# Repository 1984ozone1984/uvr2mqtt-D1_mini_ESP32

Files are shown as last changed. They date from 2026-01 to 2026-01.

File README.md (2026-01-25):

# UVR2MQTT - UVR1611 DL-Bus to MQTT Gateway

ESP32-based gateway that reads data from a Technische Alternative UVR1611 solar heating controller via DL-Bus and publishes to MQTT with Home Assistant auto-discovery.

## Hardware

- **Board**: Azdelivery D1 Mini ESP32 (ESP32-WROOM-32)
- **Connection**: DL-Bus via optocoupler to GPIO26
- **PCB Files**: KiCad schematic and PCB design files available in the `PCB/` folder, including Gerber files for manufacturing

## Features

### DL-Bus Protocol
- GPIO interrupt-based edge capture (bypasses RMT 512-symbol limitation)
- Dedicated high-priority interrupt on Core 1 (away from WiFi on Core 0)
- Manchester-like decoding with automatic polarity detection
- SYNC detection, checksum validation
- Full 64-byte frame parsing

### Sensor Data
- 16 temperature/flow/radiation sensors with configurable names
- 13 digital outputs (pumps, valves, mixers)
- 4 speed levels for variable-speed pumps
- 2 heat meters with power (kW) and energy (kWh)

### MQTT & Home Assistant
- WiFi connection with automatic reconnection
- MQTT client with Last Will and Testament (online/offline status)
- Home Assistant auto-discovery for all entities
- Configurable publish intervals
- Median filtering for sensor values
- Immediate publish on output state changes

### Web Configuration
- Built-in web UI for configuration (no rebuild required)
- WiFi STA/AP mode with automatic fallback
- Configure WiFi and MQTT settings via browser
- Edit all I/O names:
  - Sensor names (S1-S16)
  - Output names (A1-A13)
  - Speed level names (Drehzahlstufen A1, A2, A6, A7)
  - Heat meter names (WMZ1/WMZ2 power and energy)
- Disable entities by setting name to `---` or empty
- Live sensor and output status display
- Settings stored in NVS (persist across reboots)
- OTA firmware update via web browser

## Screenshots

### Web Interface - Status Page
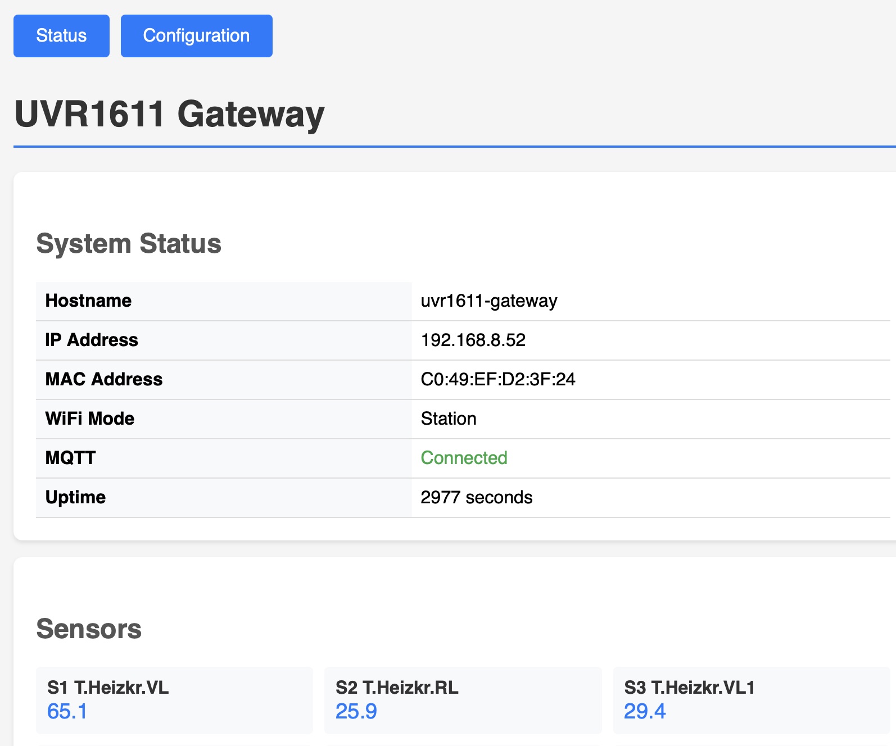
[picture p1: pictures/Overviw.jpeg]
Status Overview


### Live Sensor Data
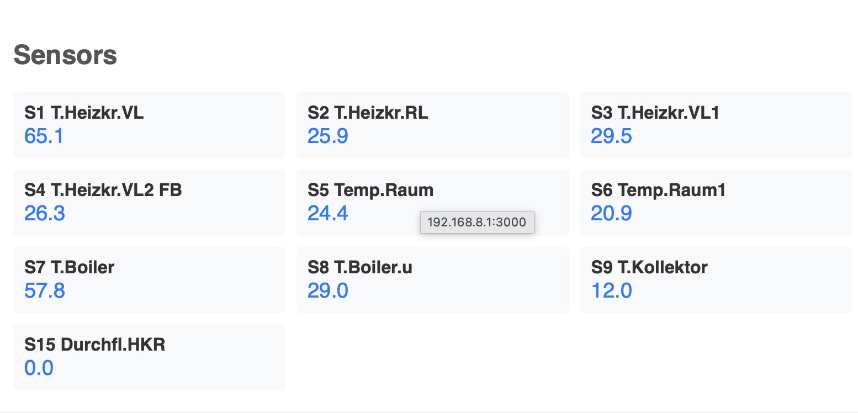
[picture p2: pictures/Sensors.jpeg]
Sensors


### Output States
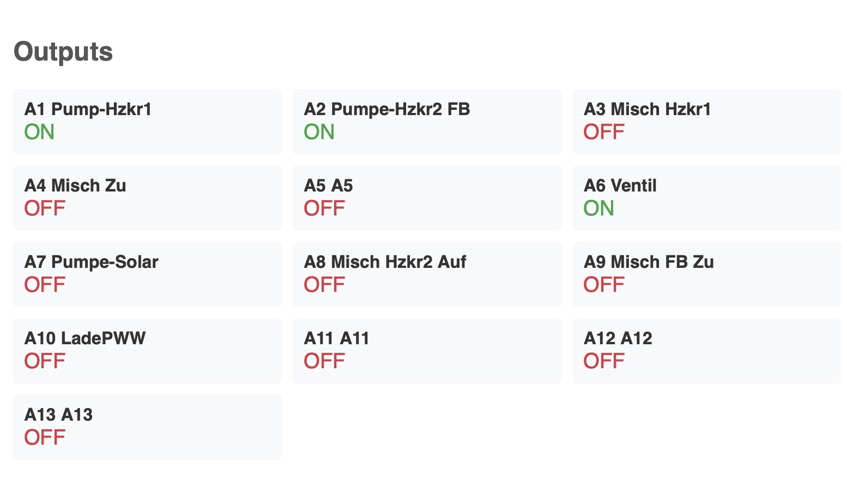
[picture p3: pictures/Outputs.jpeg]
Outputs


### WiFi Configuration
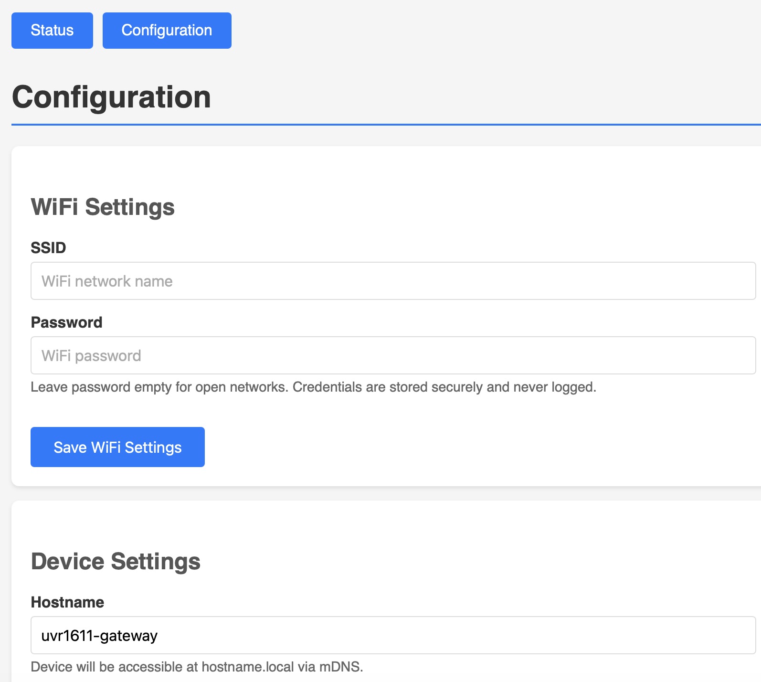
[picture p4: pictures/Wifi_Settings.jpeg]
WiFi Settings


### MQTT Configuration
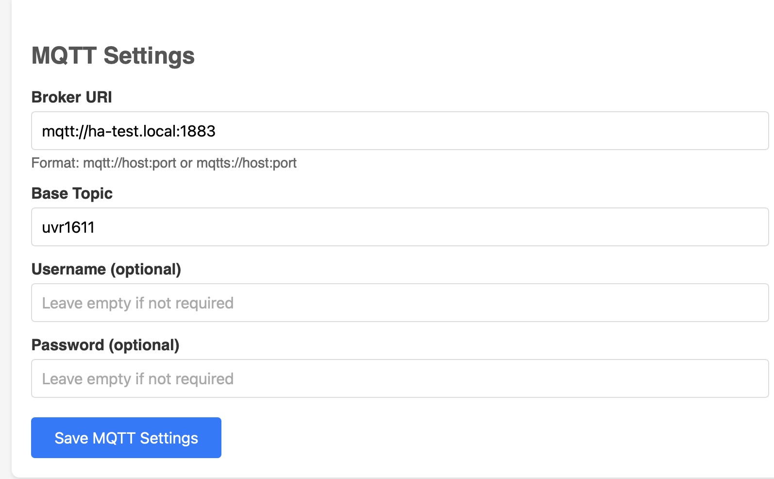
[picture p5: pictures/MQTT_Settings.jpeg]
MQTT Settings


### Home Assistant Integration
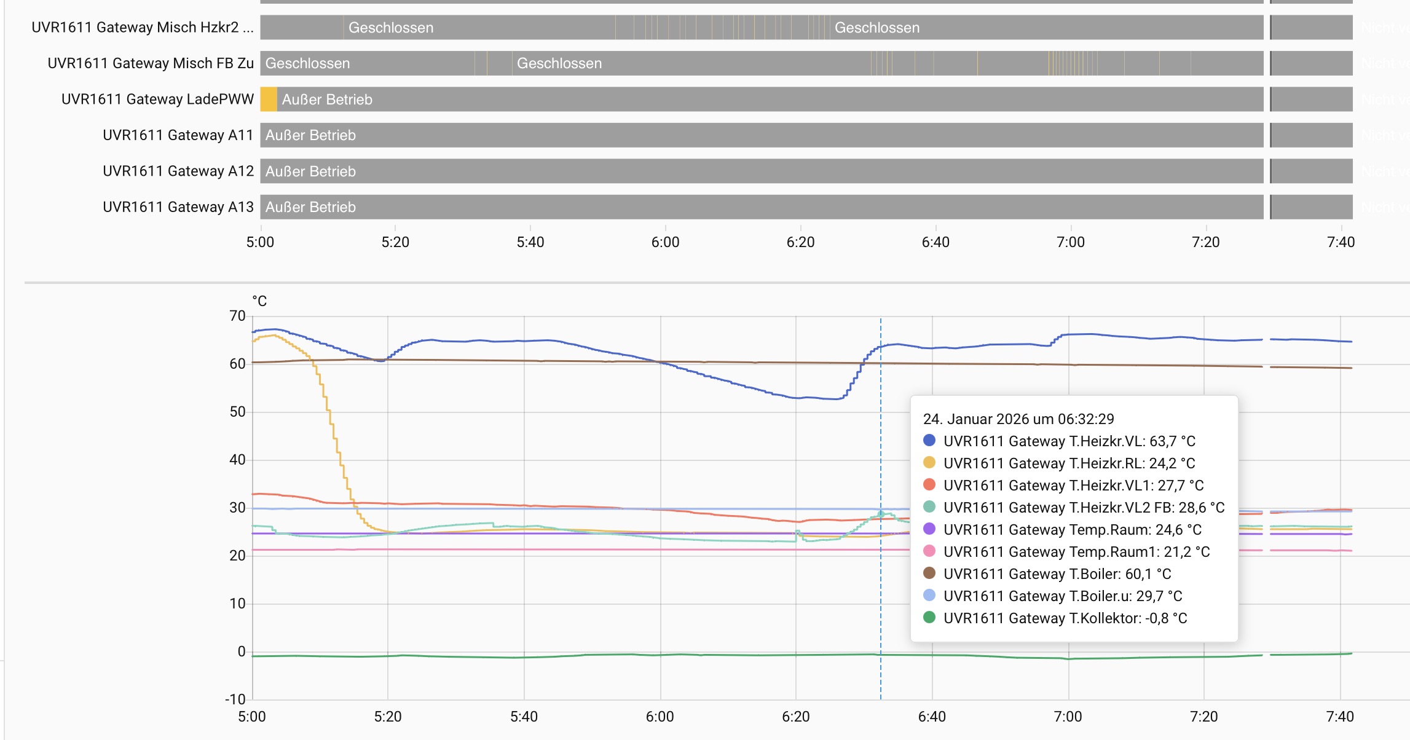
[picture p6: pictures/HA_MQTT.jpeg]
Home Assistant


## Configuration

### First Boot Setup (Web UI)

1. Flash the firmware to your ESP32
2. Device starts in AP mode (no credentials yet)
3. Connect to WiFi network **"UVR1611-XXXXXX"** (XXXXXX = last 6 chars of MAC address)
4. Open http://192.168.4.1 in your browser
5. Configure WiFi credentials and MQTT settings
6. Device saves settings and reboots
7. Device connects to your WiFi network
8. Access web UI via **http://uvr1611-gateway.local** or the device IP

### WiFi Modes

**STA Mode (Normal Operation)**:
- Connects to your configured WiFi network
- MQTT publishing active
- Web UI accessible at hostname.local

**AP Mode (Configuration/Fallback)**:
- Activates when no credentials or connection fails
- SSID: "UVR1611-XXXXXX"
- IP: 192.168.4.1
- Configure via web browser
- DL-Bus reading continues locally

### Configuring Sensors, Outputs, Speed Levels & Heat Meters

All I/O names are configurable via the web UI. **Only entities with configured names are published to MQTT and Home Assistant.** Use `---` or leave empty to disable an entity.

**Via Web UI (recommended):**
1. Go to the `/config` page
2. Scroll down to the I/O configuration section
3. Edit names for:
   - **Sensors S1-S16**: Temperature, flow, radiation sensors
   - **Outputs A1-A13**: Pumps, valves, mixers
   - **Speed Levels (Drehzahlstufen)**: Variable speed for A1, A2, A6, A7
   - **Heat Meters (Wärmemengenzähler)**: WMZ1/WMZ2 power (kW) and energy (kWh)
4. Click "Save I/O Names"
5. Changes take effect immediately for web display
6. **Reboot** to update MQTT topics and Home Assistant discovery

**Name Filtering:**
- Names must contain at least one letter or number to be published
- Names with only `-` characters (like `---`) are disabled
- Empty names are disabled
- Disabled entities do not appear in Home Assistant

**Example Configuration:**
| Entity | Name | Result |
|---|---|---|
| S1 | `T.Heizkr.VL` | ✅ Published |
| S10 | `---` | ❌ Disabled |
| S11 | ` ` (empty) | ❌ Disabled |
| WMZ1 Leistung | `Solar Leistung` | ✅ Published |
| WMZ2 Energie | `---` | ❌ Disabled |

**Via menuconfig (compile-time defaults):**
```bash
pio run -t menuconfig
```
Navigate to: "UVR1611 Configuration" → "Sensor Names", "Output Names", "Speed Level Names", or "Heat Meter Names"

### OTA Firmware Update

After initial USB flash, firmware can be updated via web browser:
1. Go to the `/config` page
2. Find "Firmware Update" section
3. Select new `.bin` firmware file
4. Click "Upload & Update Firmware"
5. Device reboots automatically with new firmware

## Building

Requires PlatformIO with ESP-IDF framework.

```bash
# Build
pio run

# Upload
pio run -t upload

# Monitor serial output
pio device monitor

# Configure sensor names
pio run -t menuconfig
```

## MQTT Topics

```
uvr1611/status                          # "online" / "offline" (LWT)
uvr1611/sensor/{sensor_name}/state      # Sensor value (median)
uvr1611/switch/{output_name}/state      # "ON" / "OFF"
uvr1611/sensor/{speed_name}/state       # Speed level (% or "inactive")
uvr1611/sensor/{hm_power_name}/state    # Heat meter power in kW
uvr1611/sensor/{hm_energy_name}/state   # Heat meter energy in kWh
uvr1611/system/mac                      # MAC address
uvr1611/system/ip                       # IP address
uvr1611/system/uptime                   # Uptime in seconds
```

Topic names are derived from configured names (lowercase, spaces/dots replaced with underscores).
Only entities with configured names (containing letters/numbers) are published.

## Home Assistant

Entities with configured names are automatically discovered via MQTT discovery. They appear under a single device with your configured hostname:
- Temperature sensors with proper device class
- Binary sensors for outputs (pumps, valves)
- Numeric sensors for speed levels (Drehzahlstufen)
- Power and energy sensors for heat meters (Wärmemengenzähler)
- System uptime sensor
- Diagnostic entities (IP address, MAC address, connectivity status)

**Note:** Only entities with names containing letters or numbers are registered. Use `---` to hide unused sensors/outputs from Home Assistant.

Change the device name by editing the hostname in the web UI and rebooting.

## Protocol Details

### DL-Bus Timing
- Display clock: 488 Hz
- Bit duration: 2.048 ms (2048 us)
- Half-bit duration: 1.024 ms (1024 us)

### Frame Structure
- SYNC: 16 high bits
- Data: 64 bytes (start bit + 8 data bits + stop bit per byte)
- Checksum: Sum of bytes 0-62 mod 256

### Sensor Types
| Type | Description | Encoding |
|---|---|---|
| 0x00 | Unused | - |
| 0x10 | Digital | Bit 7 of high byte |
| 0x20 | Temperature | 12-bit signed, /10 for °C |
| 0x30 | Flow rate | 12-bit × 4 l/h |
| 0x60 | Radiation | 12-bit W/m² |
| 0x70 | Room sensor | 9-bit signed, /10 for °C |

## Architecture

```
GPIO26 (Core 1) ─► Edge Buffer ─► Bit Extractor ─► Manchester Decoder ─► Frame Queue
                                    (Core 1)          (Core 1)              │
                                                                            ▼
WiFi/MQTT (Core 0) ◄────────────────────────────────────────────── Main Loop
```

- DL-Bus capture runs entirely on Core 1 to avoid WiFi interference
- WiFi power save disabled for consistent interrupt timing
- Dedicated GPIO interrupt (not shared ISR service) for lower latency

## Status

**All Phases Complete**:
- DL-Bus decoding: 0.2% error rate
- All sensor types parsed correctly
- MQTT publishing working
- Home Assistant auto-discovery working
- Web-based configuration UI working
- WiFi STA/AP mode with auto-fallback working
- Sensor/output name editing via web UI
- OTA firmware update via web browser

## License

MIT

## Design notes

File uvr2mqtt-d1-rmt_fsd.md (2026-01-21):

# Functional Specification Document: UVR1611 DL-Bus Reader (Simple Version)

## Project Goal
ESP32 reads UVR1611 DL-Bus data and outputs parsed values to Serial Monitor for testing and debugging.

## Hardware

### ESP32 Board
- **Azdelivery D1 Mini ESP32**
- SoC ESP32-WROOM-32
- CPU Xtensa® single-dual-core 32-bit LX6
- Chipset ESP32-D0WDQ6
- Clock frequency range 80MHz / 240MHz
- RAM 512kB
- External flash memory 4MB
- I/O pins 34
- ADC channels 18
- ADC Resolution 12-bit
- DAC channels 2
- DAC Resolution 8-bit
- Communication interfaces SPI, I2C, I2S, CAN, UART
- Max. current drawn per GPIO pin 40mA
- Wi-Fi protocols 802.11 b/g/n (802.11n up to 150 Mbps)
- Wi-Fi frequency 2.4 GHz - 2.5 GHz
- Bluetooth V4.2 - BLE and Classic Bluetooth
- Wireless antena PCB
- USB to serial chip CP2104
- Dimensions 39x28x6mm (1.5x1.1x0.2in)
- Documentation: `docs/D1 Mini ESP32_EN.pdf`

### Pin Configuration
- **DL-Bus RX Pin:** GPIO26
- **GND:** GND pin
- **Power:** 5V via USB-C or 3.3V from pin

### UVR1611 Connection
```
UVR1611 DL-Bus → Optocoupler Output → Azdelivery D1 Mini ESP32 GPIO26
                 Optocoupler GND    → Azdelivery D1 Mini ESP32 GND
```

## UVR1611 Protocol Specification

### Reference Documents
- **Protocol Specification**: `docs/Datenleitung.PDF`
- Complete DL-Bus interface documentation

### Protocol Basics
- **Display clock:** 488 Hz
- **Encoding Type:** Manchester
- **Polarity/Convention:** rising edge = 1 high
- **Sync:** 16 high bits Byte 0
- **Bit duration:** 2.048 ms
- **Frame duration:** ~1.35 seconds
- **Frame size:** 65 bytes total
- **Device ID:** 0x80 (UVR1611)
- **Device ID inverted:** 0x7F
- **Checksum:** Data Byte 64 (sum of bytes 1-63 mod 256)

sor type:**
```
x000 xxxx - Unused
x001 xxxx - Digital (Bit 7: 1=ON, 0=OFF)
x010 xxxx - Temperature (1/10 °C)
x011 xxxx - Flow rate (4 l/h)
x110 xxxx - Radiation (1 W/m²)
x111 xxxx - Room sensor (1/10 °C)
```

**Temperature Reconstruction:**
```c
if (highByte & 0x80) {  // Negative
    value = (lowByte + 256 * highByte - 65536) / 10.0;
} else {  // Positive
    value = (lowByte + 256 * highByte) / 10.0;
}
```

### Output States Decoding
**Byte 41 (Outputs A1-A8):**
```
Bit 0: Output A1
Bit 1: Output A2
Bit 2: Output A3
Bit 3: Output A4
Bit 4: Output A5
Bit 5: Output A6
Bit 6: Output A7
Bit 7: Output A8
```

**Byte 42 (Outputs A9-A13):**
```
Bit 0: Output A9
Bit 1: Output A10
Bit 2: Output A11
Bit 3: Output A12
Bit 4: Output A13
```

### Speed Levels Decoding
**Bytes 43, 44, 45, 46 (Speed levels A1, A2, A6, A7):**
```
Bits 0-4: Speed value (0-30)
Bit 5: 0 = speed control active, 1 = inactive
```

### Heat Meter Decoding
**Heat Meter Register (Byte 47):**
```
Bit 0: Heat meter 1 active
Bit 1: Heat meter 2 active
```

**Heat Meter 1 (Bytes 48-55):**
```
Bytes 48-51: Instantaneous power (1/100 kW)
  Special encoding for low_low byte
Bytes 52-53: kWh (1/10 kWh)
Bytes 54-55: MWh (1 MWh)
```

**Heat Meter 2 (Bytes 56-63):**
```
Bytes 56-59: Instantaneous power (1/100 kW)
Bytes 60-61: kWh (1/10 kWh)
Bytes 62-63: MWh (1 MWh)
```

## My UVR1611 Sensor Configuration

### Reference Documents
- **Sensor Config Page 1**: `docs/sensoren1.pdf`
- **Sensor Config Page 2**: `docs/Sensoren 2.pdf`

### Actual Sensor Mapping

**Sensors (from sensoren1.pdf & Sensoren 2.pdf):**
- **Sensor 1:** T.Heizkr.VL (Heizkreis Vorlauf) - Temperature
- **Sensor 2:** T.Heizkr.RL (Heizkreis Rücklauf) - Temperature
- **Sensor 3:** T.Heizkr.VL1 Radiatoren - Temperature
- **Sensor 4:** T.Heizkr.VL2 FB (Fußbodenheizung) - Temperature
- **Sensor 5:** Temp.Raum (Raumtemperatur) - Temperature
- **Sensor 6:** Temp.Raum1 - Temperature
- **Sensor 7:** T.Boiler - Temperature
- **Sensor 8:** T.Boiler.u (Boiler unten) - Temperature
- **Sensor 9:** T.Kollektor (Solar) - Temperature
- **Sensor 10:** --- (Unused)
- **Sensor 11:** --- (Unused)
- **Sensor 12:** --- (Unused)
- **Sensor 13:** --- (Unused)
- **Sensor 14:** --- (Unused)### Data Frame Structure
```
Byte 0:     SYNC (16 High-Bits without Start/Stop)
Byte 1:     Device ID (0x80)
Byte 2:     Device ID inverted (0x7F)
Byte 3:     Reserved (don't care)
Byte 4:     Timestamp - Minute
Byte 5:     Timestamp - Hour (Bit 5 = DST flag)
Byte 6:     Timestamp - Day
Byte 7:     Timestamp - Month
Byte 8:     Timestamp - Year (Year - 2000)
Byte 9-40:  16 Sensors (2 bytes each: Low, High)
Byte 41-42: Output states (13 outputs total)
Byte 43:    Speed level A1
Byte 44:    Speed level A2
Byte 45:    Speed level A6
Byte 46:    Speed level A7
Byte 47:    Heat meter register
Byte 48-55: Heat meter 1 data
Byte 56-63: Heat meter 2 data
Byte 64:    Checksum (sum mod 256)
```

### Sensor Data Encoding
**High-Byte bits 4-6 determine sen
- **Sensor 15:** Durchfl.HKR l/h (Durchfluss Heizkreis) - Flow rate
- **Sensor 16:** --- (Unused)

**Outputs (from sensoren1.pdf):**
- **Ausgang 1:** Pump-Hzkr1 Radiatoren (Pumpe Heizkreis 1)
- **Ausgang 2:** Pumpe-Hzkr2 FB (Pumpe Fußbodenheizung)
- **Ausgang 3:** Misch Hzkr1 Radiatore (Mischer Heizkreis 1)
- **Ausgang 4:** Zu (Mischer Zu)
- **Ausgang 5:** (Not labeled)
- **Ausgang 6:** Ventil
- **Ausgang 7:** Pumpe-Solar
- **Ausgang 8:** Misch Hzkr2 FB Auf (Mischer FB Auf)
- **Ausgang 9:** Misch FB Zu (Mischer FB Zu)
- **Ausgang 10:** LadePWW (Warmwasser Ladung)
- **Ausgang 11:** (Not labeled)
- **Ausgang 12:** (Not labeled)
- **Ausgang 13:** (Not labeled)

**Heat Meters (from Sensoren 2.pdf):**
- **Drehz A1:** --- (Speed level A1)
- **Drehz A2:** --- (Speed level A2)
- **Drehz A6:** --- (Speed level A6)
- **Drehz A7:** --- (Speed level A7)
- **Leistung 1:** 0.00 kW (Heat meter 1 power)
- **Energie 1:** 5,112.0 kWh (Heat meter 1 total energy)
- **Leistung 2:** --- (Heat meter 2 inactive)
- **Energie 2:** --- (Heat meter 2 inactive)

## Software Requirements

### Development Environment
- **PlatformIO** on local laptop (Mac)
- **Framework: ESP-IDF** (Espressif IoT Development Framework)
- **VS Code** with PlatformIO extension
- Direct USB-C connection to board
- Serial Monitor @ 115200 baud
- Code access via Samba: `smb://claude-code.local/projects/uvr2mqtt-d1-rmt`

### Firmware Features
1. Read DL-Bus on GPIO26 with RMT 
2. Custom baud rate for 488 Hz display clock
3. SYNC detection (16 High-Bits)
4. Frame reception (65 bytes)
5. Device ID validation (0x80, 0x7F)
6. Checksum validation
7. Timestamp parsing with DST flag
8. Sensor value decoding with type detection
9. Output state parsing (13 outputs)
10. Speed level parsing (A1, A2, A6, A7)
11. Heat meter 1 parsing (power, kWh, MWh)
12. Serial output with actual sensor names
13. Frame statistics and error counting

### Serial Monitor Output Format
```
==================== UVR1611 Frame #123 ====================
Timestamp: 2026-01-13 17:30:45 (DST: No)
Device ID: 0x80 (Valid)
Checksum: OK (0xAB)
Frame Time: 1347ms | Rate: 0.74 fps

TEMPERATURES:
  S1  T.Heizkr.VL:              61.0°C
  S2  T.Heizkr.RL:              54.4°C
  S3  T.Heizkr.VL1 Radiatoren:  34.9°C
  S4  T.Heizkr.VL2 FB:          39.0°C
  S5  Temp.Raum:                28.8°C
  S6  Temp.Raum1:               23.5°C
  S7  T.Boiler:                 51.6°C
  S8  T.Boiler.u:               26.0°C
  S9  T.Kollektor:              14.9°C
  S10-S14: (Unused)

FLOW RATE:
  S15 Durchfl.HKR:              0 l/h
  S16: (Unused)

OUTPUTS:
  A1  Pump-Hzkr1 Radiatoren:    AUS
  A2  Pumpe-Hzkr2 FB:           AUS
  A3  Misch Hzkr1 Radiatore:    AUS
  A4  Zu:                       AUS
  A5:                           AUS
  A6  Ventil:                   AUS
  A7  Pumpe-Solar:              AUS
  A8  Misch Hzkr2 FB Auf:       AUS
  A9  Misch FB Zu:              AUS
  A10 LadePWW:                  AUS
  A11-A13:                      AUS

SPEED LEVELS:
  A1:  --- (inactive)
  A2:  --- (inactive)
  A6:  --- (inactive)
  A7:  --- (inactive)

HEAT METER 1:
  Power:    0.00 kW
  Energy:   5112.0 kWh / 5.1 MWh

HEAT METER 2:
  (Inactive)

STATISTICS:
  Good Frames:  123
  Bad Frames:   0
  Error Rate:   0.00%
  Uptime:       2m 45s
============================================================
```

### Debug Mode Output
When debug mode is enabled, also display:
```
RAW FRAME DATA (Hex):
80 7F 00 2D 11 0D 01 1A 02 60 00 20 02 5D 01 84 00 ...
```

## Project Structure
```
uvr1611-simple/
├── uvr1611-simple_fsd.md           # This file
├── platformio.ini               # PlatformIO configuration (ESP-IDF framework)
├── main/
│   └── main.c                   # Main ESP-IDF code (C, not .cpp)
├── include/
│   ├── uvr1611_protocol.h       # Protocol definitions
│   └── sensor_names.h           # Sensor name mappings
├── docs/
│   ├── DL-Bus-Schnittstelle Datenleitung.PDF         # DL-Bus protocol spec
│   ├── D1 Mini ESP32_EN.pdf         # Hardware documentation
├── .gitignore
└── README.md
```

## Implementation Phases

### Phase 1: Basic DL-Bus reading with RMT functionality ✓
**Goal:** Receive raw data from DL-Bus
- Configure RMT on GPIO26
- Set appropriate baud rate for 488 Hz timing
- DL-Bus is a manchester code
- Receive raw bytes
- Display hex dump to Serial Monitor
- Verify data is being received

**Success:** Raw bytes visible in Serial Monitor

### Phase 2: SYNC Detection ✓
**Goal:** Identify frame boundaries
- Detect SYNC pattern (16 High-Bits)
- Mark start of frame
- Collect 65-byte frames
- Display frame boundaries

**Success:** Can identify complete frames

### Phase 3: Frame Validation ✓
**Goal:** Validate received frames
- Check Device ID (0x80)
- Check Device ID inverted (0x7F)
- Calculate checksum (sum of bytes 1-63 mod 256)
- Validate checksum against byte 64
- Count good vs bad frames
- Measure frame timing

**Success:** 100% checksum validation rate

### Phase 4: Timestamp Parsing ✓
**Goal:** Decode timestamp
- Parse minute, hour, day, month, year
- Extract DST flag from hour byte (bit 5)
- Format as readable date/time
- Display in output

**Success:** Correct date/time displayed

### Phase 5: Temperature Sensors ✓
**Goal:** Decode all 9 temperature sensors
- Parse sensor bytes (9-40, 2 bytes per sensor)
- Extract type bits (4-6 of high byte)
- Identify temperature sensors (type 0x20)
- Apply temperature reconstruction formula
- Handle positive and negative values
- Map to actual sensor names
- Display formatted values

**Success:** All 9 temps match UVR1611 display

### Phase 6: Flow Rate Sensor ✓
**Goal:** Decode flow rate sensor
- Identify flow rate type (0x30)
- Apply flow rate formula (value * 4 l/h)
- Display with sensor name

**Success:** Flow rate matches display

### Phase 7: Output States ✓
**Goal:** Decode all 13 outputs
- Parse output bytes 41-42
- Extract individual bits
- Map to output names
- Display ON/AUS states

**Success:** Output states match UVR1611

### Phase 8: Speed Levels ✓
**Goal:** Decode speed levels
- Parse speed bytes 43-46
- Extract value (bits 0-4)
- Check active flag (bit 5)
- Display values or "inactive"

**Success:** Speed levels displayed correctly

### Phase 9: Heat Meter ✓
**Goal:** Decode heat meter 1
- Check heat meter register (byte 47)
- Parse instantaneous power (bytes 48-51)
- Parse kWh (bytes 52-53)
- Parse MWh (bytes 54-55)
- Apply formulas
- Display formatted values

**Success:** Heat meter values match UVR1611

### Phase 10: Polish & Optimize ✓
**Goal:** Production-ready code
- Clean up code structure
- Add comments
- Optimize performance
- Add debug mode option
- Format output beautifully
- Add statistics
- Test stability

**Success:** Stable operation 1+ hour

## Testing Plan

### Hardware Connection Test
**Steps:**
1. ✅ Connect board to Mac via USB-C
2. ✅ Verify recognition in PlatformIO
3. ✅ Upload blink sketch
4. ✅ Verify LED blinks
5. ✅ Open Serial Monitor @ 115200
6. ✅ Verify communication

**Expected:** Basic communication works

### DL-Bus Connection Test
**Steps:**
1. ✅ Power off UVR1611
2. ✅ Connect optocoupler output to board GPIO26
3. ✅ Connect optocoupler GND to board GPIO26 GND
4. ✅ Power on UVR1611
5. ✅ Upload initial UART test code
6. ✅ Observe raw bytes in Serial Monitor

**Expected:** Receive data every ~1.35 seconds

### SYNC Detection Test
**Steps:**
1. ✅ Implement SYNC detection
2. ✅ Count detected frames
3. ✅ Verify frame rate ~0.74 fps

**Expected:** Consistent frame detection

### Checksum Validation Test
**Steps:**
1. ✅ Implement checksum calculation
2. ✅ Compare with byte 64
3. ✅ Count valid/invalid frames
4. ✅ Run for 100+ frames

**Expected:** 100% valid checksums

### Temperature Accuracy Test
**Steps:**
1. ✅ Parse all temperature sensors
2. ✅ Compare with UVR1611 display
3. ✅ Check T.Heizkr.VL (should be ~60°C)
4. ✅ Check T.Boiler (should be ~50°C)
5. ✅ Check T.Kollektor (Solar, varies)

**Expected:** Values within ±0.1°C

### Output State Test
**Steps:**
1. ✅ Parse output states
2. ✅ Compare with UVR1611 display
3. ✅ Toggle an output manually
4. ✅ Verify state change detected

**Expected:** States match exactly

### Stability Test
**Steps:**
1. ✅ Run continuously for 1 hour
2. ✅ Monitor error rate
3. ✅ Check for memory leaks
4. ✅ Verify no frame drops

**Expected:** 0% error rate, stable operation

### Load Test
**Steps:**
1. ✅ Run for 24 hours
2. ✅ Log all frames
3. ✅ Analyze statistics

**Expected:** Continuous stable operation

## Success Criteria

### Must Have (P0)
1. ✅ Receive complete DL-Bus frames
2. ✅ 100% checksum validation
3. ✅ Parse all 9 temperature sensors correctly
4. ✅ Parse flow rate sensor
5. ✅ Parse all 13 output states
6. ✅ Parse heat meter 1 data
7. ✅ Display with actual sensor names from my UVR1611
8. ✅ Values match UVR1611 display (±0.1°C)
9. ✅ Stable operation 1+ hour without errors
10. ✅ Frame rate ~0.74 fps (1.35s period)

### Should Have (P1)
1. ✅ Timestamp parsing with DST flag
2. ✅ Speed level parsing
3. ✅ Frame statistics (good/bad/error rate)
4. ✅ Formatted, readable serial output
5. ✅ Frame timing measurement

### Nice to Have (P2)
1. ⬜ Debug mode with raw hex dump
2. ⬜ Configurable output detail level
3. ⬜ LED status indicator
4. ⬜ Uptime display
5. ⬜ Average frame time calculation

## Known Sensors Summary

**Active Sensors: 10/16**
- 9 Temperature sensors (S1-S9)
- 1 Flow rate sensor (S15)
- 6 Unused sensors (S10-S14, S16)

**Active Outputs: 10/13**
- 10 Named outputs (A1-A10)
- 3 Unlabeled outputs (A11-A13)

**Heat Meters:**
- Heat meter 1: ACTIVE (5112 kWh total)
- Heat meter 2: INACTIVE

**Speed Levels:**
- A1, A2, A6, A7 available
- Currently all inactive

## Future Enhancements (Out of Scope)

### Phase 2: MQTT Publishing
- Add WiFi connection
- Publish to MQTT broker
- Home Assistant integration
- Auto-discovery

### Phase 3: OTA Programming
- ESP32 programming over Wifi

## Notes

**DL-Bus Signal Characteristics:**
- XOR with 488 Hz clock
- Inverted by output transistor
- Need to sync with display clock
- Read during second half-period of each bit

**Critical Timing:**
- Bit duration: 2.048 ms
- Baud rate calculation: 1 / 2.048ms ≈ 488 baud (approx)
- May need custom UART timing

**Checksum Calculation:**
- Sum bytes 1 through 63 (not byte 0 SYNC, not byte 64 checksum)
- Take modulo 256 (lowest 8 bits)
- Compare with byte 64

**Temperature Encoding:**
- Always check type bits (4-6) of high byte
- For negative: subtract 65536 before dividing
- Room sensors have special encoding with operating mode

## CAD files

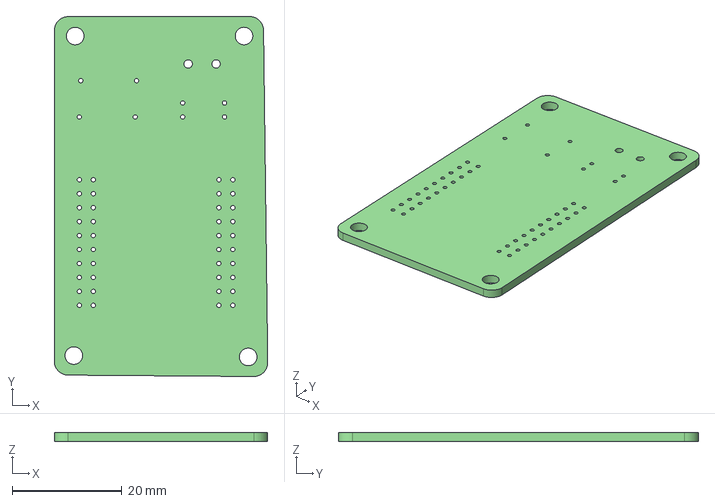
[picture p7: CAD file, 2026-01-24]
PCB/UVR2MQTT.step
38.9 x 65.5 x 1.60 mm

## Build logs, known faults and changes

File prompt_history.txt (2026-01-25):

================================================================================
UVR2MQTT-D1-RMT Project - Prompt History
================================================================================

================================================================================
ITERATION 1 - 2026-01-20
================================================================================

USER PROMPT:
------------
Make my project uvr2mqtt-d1-rmt you can find the details in uvr2mqtt-d1-rmt_fsd.md
and the needed board and DL-protocoll informations in the /docs folder
First we want only to focus on decoding the dl-bus - print raw bytes to serial
and mark syncs
No need for building I will build it on my on an external laptop with VSC and
platformio
Make a summary of what you did after each iteration including the prompt into
the file prompt_history.txt so that you can remember better what we did.

WHAT WAS DONE:
--------------
1. Read and analyzed the functional specification document (uvr2mqtt-d1-rmt_fsd.md)
2. Read and analyzed the DL-Bus protocol specification (Datenleitung.PDF)

3. Created project structure:
   - platformio.ini: ESP-IDF framework configuration for D1 Mini ESP32
   - main/main.c: Main source file with RMT-based DL-Bus decoder
   - main/CMakeLists.txt: ESP-IDF component configuration
   - prompt_history.txt: This file for tracking iterations

4. Implemented Phase 1 features in main.c:
   - RMT peripheral initialization on GPIO26
   - Raw RMT symbol capture and display
   - Two decoder approaches:
     a) Simple decoder: pulse classification and SYNC detection
     b) Frame decoder: Manchester-like decoding with phase tracking
   - SYNC detection (looking for 16 high bits = 32 half-bit pulses)
   - Raw byte printing in hex format with key byte identification
   - Basic checksum calculation
   - Statistics tracking (SYNC count, frame count, errors)

KEY PROTOCOL DETAILS EXTRACTED:
-------------------------------
- UVR1611 uses 488 Hz display clock
- Bit duration: 2.048 ms (2048 µs)
- Half-bit duration: 1.024 ms (1024 µs)
- Data is XOR'd with clock, then inverted by output transistor
- SYNC: 16 high bits without start/stop bit
- Byte format: 1 start bit (0), 8 data bits (LSB first), 1 stop bit (1)
- Frame: 65 bytes total (SYNC + 64 data bytes including checksum)
- Device ID: 0x80, inverted: 0x7F
- Checksum: sum of bytes 1-63 mod 256

FILES CREATED:
--------------
- /home/stefan/projects/uvr2mqtt-d1-rmt/platformio.ini
- /home/stefan/projects/uvr2mqtt-d1-rmt/main/main.c
- /home/stefan/projects/uvr2mqtt-d1-rmt/main/CMakeLists.txt
- /home/stefan/projects/uvr2mqtt-d1-rmt/prompt_history.txt

NEXT STEPS (for future iterations):
------------------------------------
1. Build and test on actual hardware
2. Fine-tune timing tolerances based on real signal
3. Improve SYNC detection algorithm if needed
4. Implement proper Manchester decoding based on observed signal patterns
5. Add frame validation (device ID check, checksum verification)
6. Move to Phase 2: Full frame parsing with sensor data decoding

================================================================================
ITERATION 1.1 - 2026-01-20 (Bugfix)
================================================================================

USER FEEDBACK:
--------------
Build failed with "Error: Missing the `src` folder with project sources."

FIX APPLIED:
------------
- Renamed `main/` folder to `src/` (PlatformIO expects src folder, not main)
- Removed CMakeLists.txt (PlatformIO handles this automatically)
- Added `src_dir = src` to platformio.ini
- Changed build flag from LOG_LOCAL_LEVEL to CONFIG_LOG_DEFAULT_LEVEL

NEW PROJECT STRUCTURE:
----------------------
uvr2mqtt-d1-rmt/
├── platformio.ini
├── src/
│   └── main.c
├── docs/
├── prompt_history.txt
└── uvr2mqtt-d1-rmt_fsd.md

================================================================================
ITERATION 1.2 - 2026-01-20 (Additional fixes)
================================================================================

ISSUES FIXED:
-------------
1. Git repository issues - ESP-IDF CMake requires git metadata
   - User initialized git repo in project and framework directories
   - Cleaned .pio folder to clear stale cache

2. Missing partition table file
   - Removed `board_build.partitions = default.csv` from platformio.ini

3. Compiler errors
   - Changed `%u` to `%lu` with casts for uint32_t format specifiers
   - Removed unused `frame_byte_count` and `in_sync` variables
   - Fixed unsigned comparison issue (accumulated < 0)
   - Removed CONFIG_LOG_DEFAULT_LEVEL build flag (redefinition)

4. Runtime error: RMT channel state issue
   - After timeout, rmt_receive() failed with "channel not in enable state"
   - Fixed by adding rmt_disable/rmt_enable cycle after timeouts

================================================================================
ITERATION 1.3 - 2026-01-20 (Debug DL-Bus no data)
================================================================================

USER FEEDBACK:
--------------
DL-Bus is connected but no data received (continuous timeouts).
User confirms: "yes bus is connected board works with an other project please
add more debuging to find the cause"

DEBUGGING ADDED:
----------------
1. GPIO level monitoring functions:
   - read_gpio_level(): Read raw GPIO state
   - debug_gpio_activity(): Monitor GPIO for transitions over a time period
     - Counts samples, transitions, high/low ratio
     - Warns if no transitions detected (signal issue)

2. init_gpio_debug(): Configure GPIO with internal pull-up before RMT takes over

3. Enhanced startup sequence:
   - Initialize GPIO for debugging first
   - Run 500ms GPIO activity monitor before RMT init
   - Print initial GPIO level

4. Enhanced main loop:
   - Print GPIO level before each receive attempt
   - Print GPIO level at timeout
   - Every 3 timeouts, disable RMT and run GPIO activity check
   - Track timeout count for diagnostics

5. Added esp_rom_sys.h include for esp_rom_delay_us

DIAGNOSTIC OUTPUT:
------------------
The new debugging will show:
- Whether the GPIO sees any signal activity at all
- The idle level of the bus (high or low)
- Transition count to verify data is being transmitted
- Helps distinguish between:
  a) No signal on GPIO (wiring/connection issue)
  b) Signal present but RMT not capturing (config issue)

================================================================================
ITERATION 1.4 - 2026-01-20 (RMT config fixes, buffer increase)
================================================================================

USER FEEDBACK:
--------------
1. Error: signal_range_max_ns too big (max 65535000 ns)
   - Fixed: reduced from 100ms to 50ms, then to 5ms

2. GPIO activity confirmed - signal IS present on GPIO26:
   - 375-410 transitions in 500ms
   - ~50/50 high/low ratio
   - Signal activity detected

3. RMT started receiving data after fixing idle threshold

FIXES APPLIED:
--------------
1. signal_range_max_ns: 100000000 → 50000000 → 5000000 ns (5ms idle threshold)
2. signal_range_min_ns: 1000 → 100 ns (more permissive)
3. RMT buffer: 256 → 512 symbols
4. rx_symbols array: 256 → 512 elements
5. Added callback counter for debugging
6. Improved simple decoder with pulse analysis and bit extraction

RESULTS:
--------
- RMT now receiving 448-492 symbols per capture
- Decoding 52-58 bytes per frame (close to full 64 bytes)
- SYNC detection working (32-35 half-bits detected)
- One frame showed correct inverted ID: "Byte 2: 0x7F (OK)"

CURRENT STATE - END OF DAY 1:
-----------------------------
RMT capture is working well. Main remaining issue is byte decoding accuracy.

Observations from final log:
1. Device ID varies: 0x40, 0xBF, 0x5F, 0xEF, 0x7F, 0x17, 0xC5, etc.
2. Expected: Device ID 0x80, inverted 0x7F
3. One frame showed 0xEF with 0x7F (OK) - partial success
4. Repeating patterns visible: AF 50 AF 50... or 51 51 51 51... (likely sensor data)
5. Signal polarity varies based on capture start point

Key insight: When we got "Byte 2: 0x7F (OK)", byte 1 was 0xEF (not 0x80).
This means our bit decoding has phase/alignment issues.

ANALYSIS FOR TOMORROW:
----------------------
The frame decoder using half-bit counting approach is partially working:
- SYNC detection: WORKING (32-35 half-bits)
- Frame capture: WORKING (50+ bytes)
- Byte decoding: NEEDS FIX (bit alignment/phase issues)

The DL-Bus encoding (XOR with 488 Hz clock + transistor inversion):
- "1" bit: HIGH (1024µs) then LOW (1024µs)
- "0" bit: LOW (1024µs) then HIGH (1024µs)
- SYNC (16 ones): alternating 1024µs pulses
- After SYNC, start bit (0) causes phase shift (LONG pulse ~2048µs)

Probable issues with current decoder:
1. Bit sampling point may be off (should sample at bit boundary, not mid-bit)
2. Phase tracking after SYNC transition not handled correctly
3. May need to invert decoded bits or handle signal polarity

Raw timing is excellent:
- Short pulses: 968-1034 µs (target: 1024 µs) ✓
- Long pulses: 1969-2035 µs (target: 2048 µs) ✓

TODO FOR NEXT SESSION:
----------------------
1. Fix bit decoding phase alignment in decode_dlbus_frame()
2. Handle the SYNC → start bit transition (long pulse marks phase change)
3. Consider signal polarity (sometimes H>L, sometimes L>H)
4. Test with proper byte alignment to get 0x80 0x7F as first two bytes
5. Once decoding works, implement checksum verification
6. Parse sensor data fields per protocol specification

COMPILER WARNING (expected):
----------------------------
decode_dlbus_simple defined but not used - we switched to frame decoder only

================================================================================
ITERATION 2 - 2026-01-21 (Pipeline Architecture Refactor)
================================================================================

USER PROMPT:
------------
I would like to improve the code in that way: RMT Hardware reads edges -> raw edge
buffer as a circular buffer big enough to capture at least 1.5 DL_Bus frames ->
bit extracting as a task -> Manchester decoding as a task -> DL-Bus Frames as a result

WHAT WAS DONE:
--------------
Complete architectural refactor from monolithic to pipeline-based design.

NEW ARCHITECTURE:
-----------------
1. RMT Hardware -> Edge Circular Buffer (1024 entries, ~1.5 frames)
2. Bit Extractor Task -> Bit Queue (1024 entries)
3. Manchester Decoder Task -> Frame Queue (3 frames)
4. Main Task -> Displays frames and statistics

COMPONENTS CREATED:

1. Edge Circular Buffer (edge_buffer_t):
   - Stores pulse durations with level (HIGH/LOW)
   - Size: 1024 entries (~1.5 frames worth)
   - Lock-free single-producer/single-consumer safe design
   - Mutex for batch operations from RMT callback
   - Binary semaphore for data-ready signaling

2. RMT Receive Task (rmt_receive_task):
   - Priority 10 (highest)
   - Continuously receives RMT symbols
   - Copies symbols to edge circular buffer
   - Signals bit extractor when data available

3. Bit Extractor Task (bit_extractor_task):
   - Priority 8
   - Reads edges from circular buffer
   - Classifies pulses: SHORT (~1024us), LONG (~2048us), INVALID
   - Counts half-bits and extracts bits at 2-half-bit boundaries
   - Handles gaps (>5ms) by resetting state
   - Outputs bit_entry_t to bit_queue

4. Manchester Decoder Task (manchester_decoder_task):
   - Priority 6
   - State machine: HUNTING_SYNC -> IN_BYTE
   - Detects SYNC: 16+ consecutive 1s (or 0s if inverted)
   - Handles polarity inversion automatically
   - Assembles bytes: start(0) + 8 data bits (LSB first) + stop(1)
   - Validates checksum (sum of bytes 0-62 mod 256)
   - Outputs dlbus_frame_t to frame_queue

5. Main Task (app_main loop):
   - Receives frames from frame_queue
   - Prints decoded frames with key fields
   - Shows timestamp if available
   - Prints pipeline statistics every 10 seconds

DATA STRUCTURES:
----------------
- edge_t: {duration, level}
- bit_entry_t: {value, is_sync}
- dlbus_frame_t: {data[64], length, valid, timestamp}

BUFFER SIZING:
--------------
- Frame = 64 bytes x 10 bits x ~2 pulses/bit = ~1280 pulses
- Edge buffer: 1024 entries (safety margin)
- Bit queue: 1024 entries
- Frame queue: 3 entries

STATISTICS TRACKED:
-------------------
- stat_edges_received
- stat_bits_extracted
- stat_syncs_detected
- stat_frames_decoded
- stat_frames_valid
- Buffer fill levels

BENEFITS OF NEW ARCHITECTURE:
-----------------------------
1. Separation of concerns - each task has single responsibility
2. Better buffering - circular buffer prevents data loss
3. Async processing - tasks run independently
4. Easier debugging - statistics show pipeline health
5. More robust - gaps and noise handled gracefully
6. Extensible - easy to add processing stages

FILES MODIFIED:
---------------
- /home/stefan/projects/uvr2mqtt-d1-rmt/src/main.c (complete rewrite)
- /home/stefan/projects/uvr2mqtt-d1-rmt/prompt_history.txt (this update)

NEXT STEPS:
-----------
1. Build and test on hardware
2. Tune timing tolerances if needed
3. Fix any bit extraction/decoding issues based on results
4. Add more detailed frame parsing (sensors, outputs, etc.)
5. Consider adding debug output for individual stages

================================================================================
ITERATION 2.1 - 2026-01-21 (RMT Buffer Limitation Discovery & GPIO Solution)
================================================================================

USER PROMPT:
------------
[User provided actual log output showing frames timing out at byte 60]
"constantly failing at byte30" / "byte0 and byte1 look correct but we still get
the frame timeout" / "is there no way for continuous rmt receiving?"

PROBLEM DISCOVERED:
-------------------
ESP32 RMT peripheral has a fundamental limitation without DMA:
- Maximum 512 symbols (8 memory blocks × 64 symbols)
- Full DL-Bus frame needs ~656 symbols (16 SYNC + 64 bytes × 10 bits)
- Could only capture ~60 bytes (512 symbols) before buffer filled
- Double-buffering attempted but gaps between captures caused data loss
- ESP32-WROOM-32 does NOT support DMA for RMT (only ESP32-S2/S3/C3)

SOLUTION IMPLEMENTED:
---------------------
Replaced RMT peripheral with GPIO interrupt-based edge capture:

1. GPIO Interrupt Handler (gpio_isr_handler):
   - Fires on every edge (rising AND falling) using GPIO_INTR_ANYEDGE
   - Captures timestamp via esp_timer_get_time() (microsecond precision)
   - Calculates pulse duration since last edge
   - Stores directly to circular buffer
   - NO BUFFER SIZE LIMIT - limited only by software buffer (2048 entries)
   - Fast execution (~1ms pulses = plenty of time for ISR)

2. Removed all RMT code:
   - No rmt_rx.h include
   - No RMT channel, callbacks, or tasks
   - No hardware buffer limitations

3. Pipeline now:
   GPIO ISR → Edge Buffer → Bit Extractor Task → Manchester Decoder → Frames

RESULTS:
--------
- FULL 64-byte frames captured successfully
- Checksum validation: VALID
- Device ID: 0x80 (UVR1611) ✓
- Inverted ID: 0x7F ✓
- Timestamp decoded correctly
- Statistics show 665 bits per frame (640 needed + SYNC)
- No frames dropped, no partial frames

SAMPLE OUTPUT:
--------------
========================================
DL-BUS FRAME (tick=284)
========================================
RAW (64 bytes):
80 7F 0F 1C 11 15 01 1A 04 22 00 21 14 21 FD 20
F5 72 D5 20 00 22 86 20 F8 AF 00 00 00 00 00 00
00 00 00 00 00 30 00 00 23 00 9E 9E 9E 80 01 00
00 00 00 8E 17 0F 00 02 00 02 00 00 3E 0A 3C B9

Key Fields:
  Device ID:     0x80 (UVR1611)
  ID Inverted:   0x7F (OK)
  Checksum:      VALID
  Time:          2026-01-21 17:28 (DST:0)
========================================

FILES MODIFIED:
---------------
- src/main.c: Replaced RMT with GPIO interrupt capture
- prompt_history.txt: This update

KEY LEARNINGS:
--------------
1. ESP32 RMT without DMA is limited to 512 symbols max
2. Double-buffering doesn't help when signal is continuous
3. GPIO interrupts are better for slow protocols (~1ms pulses)
4. esp_timer_get_time() provides microsecond-precision timestamps
5. ISR-based capture has no inherent buffer limit

PHASE 1 STATUS: COMPLETE ✓
--------------------------
All Phase 1 requirements met:
- [x] DL-Bus signal capture
- [x] SYNC detection
- [x] Full frame reception (64 bytes)
- [x] Checksum validation
- [x] Device ID verification
- [x] Timestamp parsing

NEXT STEPS:
-----------
1. Parse sensor values (temperatures, flow rate)
2. Parse output states (A1-A13)
3. Parse speed levels and heat meters
4. Clean up debug output
5. Consider MQTT integration (Phase 2)

================================================================================
ITERATION 3 - 2026-01-22 (I/O Configuration & Sensor Parsing)
================================================================================

USER PROMPT:
------------
"looks good now lets add a file with which we can set the configuration of our
sensor and outputs etc it should have this content the name should be io-config
and be editable before build by user"

[User provided sensor names S1-S16, output names A1-A13, speed level names,
and sensor unit strings]

"please make an esp-idf conform config"
"yes restructure for native esp-idf"
"I still want to build with platformio"
"so now map all values to the corresponding sensors, pumps ..."

WHAT WAS DONE:
--------------

1. Created ESP-IDF Kconfig Configuration:
   - src/Kconfig.projbuild: Full menuconfig integration with:
     - Sensor Names menu (S1-S16) with German labels
     - Output Names menu (A1-A13)
     - Speed Level Names menu (A1, A2, A6, A7)
     - Sensor Units menu (by type: unused, digital, temp, flow, radiation, room)
   - src/io_config.h: Header providing array macros from Kconfig values

2. Project Structure (kept PlatformIO compatible):
   uvr2mqtt-D1_mini_ESP32/
   ├── platformio.ini          # PlatformIO config (framework = espidf)
   ├── src/
   │   ├── main.c              # Main application
   │   ├── Kconfig.projbuild   # Menuconfig definitions
   │   └── io_config.h         # Config arrays from Kconfig
   └── ...

3. Added Frame Parsing to main.c:

   Frame Byte Offsets (UVR1611 Protocol):
   - Bytes 0-1: Device ID (0x80) and inverted (0x7F)
   - Bytes 3-7: Timestamp (minute, hour, day, month, year)
   - Bytes 8-39: 16 sensors (2 bytes each: low, high)
   - Bytes 40-41: Output states (A1-A8, A9-A13)
   - Bytes 42-45: Speed levels (A1, A2, A6, A7)
   - Byte 46: Heat meter register
   - Bytes 47-54: Heat meter 1 data
   - Bytes 55-62: Heat meter 2 data
   - Byte 63: Checksum

   Parsing Functions Added:
   - get_sensor_type(): Extract type from high byte bits 4-6
   - get_sensor_unit(): Get unit string for sensor type
   - decode_sensor_value(): Decode value based on type (temp, flow, etc.)
   - is_output_on(): Check output state from bytes 40-41
   - decode_speed_level(): Parse speed value and active flag
   - decode_heat_power(): Decode instantaneous power (kW)
   - decode_heat_energy(): Decode total energy (kWh)

   Updated print_frame():
   - Shows all 16 sensors with configured names and units
   - Shows all 13 outputs with ON/OFF (EIN/AUS) state
   - Shows 4 speed levels with active/inactive status
   - Shows both heat meters with power and energy
   - Skips sensors marked as "---" (unused)

4. Fixed Room Sensor Decoding Bug:

   USER FEEDBACK:
   "S5 Temp.Raum: 76.5 C is showing a wrong value in reality it has 25.3 C"

   ROOT CAUSE:
   - Room sensors (type 0x70) have different encoding than temperature sensors
   - Bits 0-3 of high byte contain operating mode, NOT temperature data
   - Was incorrectly reading 12-bit value (765) instead of 8-bit (253)
   - Difference: 765 - 253 = 512 = bit 9 (from high byte bit 1)

   FIX APPLIED:
   - Temperature sensors (0x20): 12-bit value (low byte + bits 0-3 of high byte)
   - Room sensors (0x70): 8-bit value (low byte only)
   - After fix: S5 Temp.Raum correctly shows 25.3°C

SAMPLE OUTPUT (after fix):
--------------------------
==================== UVR1611 Frame #78 ====================
Timestamp: 2026-01-22 17:21 (DST: No)
Device ID: 0x80 (Valid)
Checksum:  OK

SENSORS:
--------
  S1  T.Heizkr.VL     :   59.9 C
  S2  T.Heizkr.RL     :   25.9 C
  S5  Temp.Raum       :   25.3 C   <-- Fixed!
  S7  T.Boiler        :   50.7 C
  S15 Durchfl.HKR     :      0 l/h

OUTPUTS:
--------
  A1  Pump-Hzkr1      : EIN
  A2  Pumpe-Hzkr2 FB  : EIN
  A6  Ventil          : EIN
  ...

SPEED LEVELS:
-------------
  Drehz A1        : 30
  Drehz A2        : 30
  Drehz A6        : 30
  Drehz A7        : 0

HEAT METERS:
------------
  Heat Meter 1:
    Power:     0.00 kW
    Energy:   15640.0 kWh (15.6 MWh)
============================================================

CONFIGURATION USAGE:
--------------------
Run: pio run -t menuconfig
Navigate to: "UVR1611 I/O Configuration"
Edit sensor/output names as needed, then build.

FILES CREATED/MODIFIED:
-----------------------
- src/Kconfig.projbuild (new): Menuconfig definitions
- src/io_config.h (new): Config array macros
- src/main.c (modified): Added parsing functions and updated print_frame()
- prompt_history.txt (modified): This update

NEXT STEPS:
-----------
1. Add MQTT publishing (Phase 2)
2. Add WiFi configuration
3. Home Assistant auto-discovery
4. OTA updates (Phase 3)

================================================================================
ITERATION 4 - 2026-01-22 (MQTT & Home Assistant Integration)
================================================================================

USER PROMPT:
------------
"Let's proceed with MQTT. Therefore make a new Github branch. I want to have my
wifi settings, hostname and mqtt settings in a config file which is not uploaded
to github - please add an example file instead all with esp-idf best known method.
Also add Homeassistant autodiscovery. I want to publish the Sensor values every
30 seconds (publish intervals should be set in config file) The value to be
published should be the median of the values received until last publish.
For the pump readings publish immediately when the value changes or on publish
interval. Also publish Mac and IP address via MQTT. And add Mqtt Status so that
homeassistant knows the on/offline status"

WHAT WAS DONE:
--------------

1. Created new Git branch: feature/mqtt-homeassistant

2. Created WiFi/MQTT Configuration System:
   - src/wifi_config.h.example: Template with all settings (excluded from git)
   - Added src/wifi_config.h to .gitignore to protect credentials

   Configuration options in wifi_config.h:
   - WIFI_SSID, WIFI_PASSWORD
   - DEVICE_HOSTNAME
   - MQTT_BROKER_URI, MQTT_USERNAME, MQTT_PASSWORD
   - MQTT_BASE_TOPIC, HA_DISCOVERY_PREFIX
   - PUBLISH_INTERVAL_SENSORS_S (default: 30s)
   - PUBLISH_INTERVAL_OUTPUTS_S (default: 30s)
   - PUBLISH_INTERVAL_SYSTEM_S (default: 60s)
   - HA_DISCOVERY_INTERVAL_S (default: 300s)
   - MQTT_QOS, MQTT_RETAIN settings

3. Created MQTT & Home Assistant Module:

   src/mqtt_ha.h - Header with:
   - Sensor buffer structure for median calculation
   - Output/speed state tracking structures
   - System info structure (MAC, IP, uptime)
   - Function declarations for all MQTT operations

   src/mqtt_ha.c - Implementation with:
   - WiFi connection with retry logic
   - MQTT client with Last Will and Testament (LWT) for online/offline status
   - Median calculation using qsort for sensor values
   - Change detection for outputs (publish immediately on change)
   - Change detection for speed levels (publish immediately on change)
   - Home Assistant auto-discovery for all entities:
     * Temperature sensors with device_class
     * Flow sensors
     * Binary sensors for outputs (pumps, valves, mixers)
     * Speed level sensors
     * Heat meter power and energy sensors
     * System uptime sensor
   - System info publishing (MAC, IP, uptime)
   - Configurable publish intervals

4. Updated main.c:
   - Added mqtt_ha.h include
   - Added process_frame_for_mqtt() function that:
     * Extracts sensor values and adds to median buffer
     * Updates output states (triggers immediate publish on change)
     * Updates speed levels (triggers immediate publish on change)
     * Publishes heat meter data
   - Modified app_main() to initialize MQTT/WiFi on startup
   - Modified main loop to:
     * Process frames for MQTT
     * Call mqtt_ha_loop() for interval-based publishing
     * Show MQTT connection status in statistics

MQTT TOPIC STRUCTURE:
---------------------
uvr1611/status                      -> "online" / "offline" (LWT)
uvr1611/sensor/{name}/state         -> Sensor value (median)
uvr1611/switch/{name}/state         -> "ON" / "OFF"
uvr1611/sensor/heat_meter_1_power/state -> Power in kW
uvr1611/sensor/heat_meter_1_energy/state -> Energy in kWh
uvr1611/system/mac                  -> MAC address
uvr1611/system/ip                   -> IP address
uvr1611/system/uptime               -> Uptime in seconds

HOME ASSISTANT DISCOVERY:
-------------------------
Auto-discovery messages published to:
homeassistant/sensor/{device_id}/{sensor_id}/config
homeassistant/binary_sensor/{device_id}/{output_id}/config

Features:
- Device grouping (all entities under "UVR1611 Gateway")
- Proper device_class for temperature, power, energy
- Availability based on uvr1611/status topic
- Unique IDs for each entity

PUBLISH BEHAVIOR:
-----------------
- Sensors: Median of all samples since last publish, every 30s (configurable)
- Outputs: Immediately on state change, also every 30s
- Speed levels: Immediately on change, also every 30s
- Heat meters: Every frame (if active)
- System info: Every 60s (configurable)
- HA discovery: On connect, then every 300s (configurable)

FILES CREATED/MODIFIED:
-----------------------
- src/wifi_config.h.example (new): Configuration template
- src/mqtt_ha.h (new): MQTT module header
- src/mqtt_ha.c (new): MQTT module implementation (~650 lines)
- src/main.c (modified): MQTT integration
- .gitignore (modified): Added src/wifi_config.h

USAGE:
------
1. Copy wifi_config.h.example to wifi_config.h
2. Edit wifi_config.h with your WiFi and MQTT credentials
3. Build and flash
4. Device will connect to WiFi, then MQTT
5. Home Assistant will auto-discover all entities

NEXT STEPS:
-----------
1. Test on hardware with actual MQTT broker
2. Fine-tune publish intervals if needed
3. Add OTA updates (Phase 3)
4. Consider adding web configuration interface

================================================================================
ITERATION 5 - 2026-01-23 (WiFi Interference Fix)
================================================================================

USER PROMPT:
------------
[User provided device monitor output showing two issues:]
1. "Guru Meditation Error: Core 0 panic'ed (Cache error). Cache disabled but
   cached memory region accessed" - Crash during NVS flash init
2. After fixing crash: DL-Bus reading became unreliable with >90% error rate
   (was <1% before WiFi/MQTT implementation)
   - Many "Bad stop bit" errors throughout frames
   - Corrupted data, invalid checksums

PROBLEMS IDENTIFIED:
--------------------

Problem 1: Cache Error Crash
- GPIO ISR called gpio_get_level() which accesses flash memory
- During nvs_flash_init(), flash cache is disabled for read operations
- When GPIO interrupt fired during NVS init, ISR tried to access flash → crash

Problem 2: WiFi Timing Interference
- WiFi interrupts cause variable latency in GPIO ISR execution
- Pulse duration measurements were getting stretched/compressed
- Bit boundary detection was off, causing "bad stop bit" errors
- Statistics showed short:long pulse ratio of 3.25:1 (should be ~1:1)

FIXES APPLIED:
--------------

1. IRAM-Safe GPIO Read (main.c):
   - Added: #include "soc/gpio_struct.h"
   - Changed ISR from: int level = gpio_get_level(DL_BUS_GPIO);
   - To direct register: int level = (GPIO.in >> DL_BUS_GPIO) & 1;
   - Direct register access is IRAM-safe (no flash access needed)

2. Increased Timing Tolerance (main.c):
   - TOLERANCE_US: 200us → 350us
   - SHORT_PULSE: 674-1374us (was 824-1224us)
   - LONG_PULSE: 1698-2398us (was 1848-2248us)
   - Added PULSE_MIDPOINT (1536us) for gap classification

3. Mid-Gap Pulse Classification (main.c):
   - Pulses between SHORT_PULSE_MAX and LONG_PULSE_MIN are now classified
     by proximity (closer to short → short, closer to long → long)
   - This handles WiFi-induced timing jitter gracefully
   - Added stat_midgap_pulses counter to track WiFi interference level

4. Dedicated GPIO Interrupt (main.c):
   - Replaced gpio_install_isr_service() + gpio_isr_handler_add() with
     direct esp_intr_alloc() for lower latency
   - Created gpio_dedicated_isr() that clears interrupt and calls handler
   - Removes ISR dispatcher overhead

5. GPIO Interrupt Pinned to Core 1 (main.c):
   - Added core1_init_task() that runs on Core 1
   - esp_intr_alloc() pins interrupts to calling core
   - GPIO interrupt now runs on Core 1, away from WiFi (Core 0)
   - Uses semaphore to synchronize initialization

6. WiFi Power Save Disabled (mqtt_ha.c):
   - Added: ESP_ERROR_CHECK(esp_wifi_set_ps(WIFI_PS_NONE));
   - Disables WiFi power save mode
   - Reduces periodic WiFi interrupts that cause timing jitter

7. Early Frame Rejection (main.c):
   - Added MAX_STOP_BIT_ERRORS (8) threshold
   - Frames with too many stop bit errors are abandoned early
   - Only first 3 stop bit errors per frame are logged (reduces spam)
   - Added stop_bit_errors counter reset on SYNC detection

STATISTICS UPDATE:
------------------
- Statistics now show: "Pulses: short=X, long=Y, midgap=Z, invalid=W"
- midgap count indicates how much WiFi jitter is being compensated

FILES MODIFIED:
---------------
- src/main.c:
  * Added soc/gpio_struct.h and esp_intr_alloc.h includes
  * Added PULSE_MIDPOINT constant
  * Added stat_midgap_pulses counter
  * Added gpio_intr_handle variable
  * Added gpio_dedicated_isr() function
  * Modified init_gpio_capture() for dedicated interrupt
  * Added core1_init_task() for Core 1 interrupt allocation
  * Modified classify_pulse() with mid-gap classification
  * Modified manchester_decoder_task() with stop_bit_errors tracking
  * Updated statistics printout with midgap count
  * Modified app_main() to init GPIO interrupt from Core 1

- src/mqtt_ha.c:
  * Added esp_wifi_set_ps(WIFI_PS_NONE) after WiFi config

TECHNICAL DETAILS:
------------------
ESP32 has two cores:
- Core 0: Handles WiFi/BT protocol stack, causes frequent interrupts
- Core 1: Available for application, more predictable timing

GPIO interrupt priorities:
- Level 1-3: Can be handled by C code
- Level 4-5: Require assembly handlers
- We use Level 3 (highest practical for C code)

WiFi interference sources:
- WiFi power save causes periodic wake/sleep cycles
- WiFi TX/RX interrupts have high priority
- Flash operations during WiFi credentials access

RESULTS:
--------
- Error rate: 0.00% (all frames valid)
- MQTT connected and publishing
- WiFi interference successfully mitigated
- Only 1-2 midgap pulses per ~90,000 edges (negligible jitter)

================================================================================
ITERATION 5.1 - 2026-01-23 (Room Sensor Fix & Code Cleanup)
================================================================================

USER FEEDBACK:
--------------
"S5 Temp.Raum shows 0.7 C in reality it has 26.1"

PROBLEM:
--------
Room sensor showing 0.5-0.7°C instead of actual 26.1°C.
- Value 261 (26.1°C) requires 9 bits
- Previous fix only read 8 bits (low byte), giving 5 (0.5°C)
- Missing bit 8 (the 256)

ROOT CAUSE ANALYSIS:
--------------------
Room sensor encoding uses 9 bits, not 8:
- Low byte (8 bits) + bit 0 of high byte (1 bit) = 9 bits
- Bits 1-3 of high byte contain operating mode (not temperature)
- Range: -51.1°C to +51.1°C (values -511 to +511)

The original bug (iteration 3) was reading 12 bits which included mode bits.
The fix went too far by only reading 8 bits.

FIX APPLIED:
------------
Changed SENSOR_TYPE_ROOM decoding in main.c:
- OLD: int16_t raw_value = low_byte;
- NEW: int16_t raw_value = low_byte | ((high_byte & 0x01) << 8);
- Two's complement adjusted from 256 to 512 for 9-bit values

CODE CLEANUP:
-------------
1. Removed unused edge_buffer_put() function (was causing compiler warning)
2. Simplified gpio_dedicated_isr() - removed unnecessary branch for GPIO >= 32
   (GPIO26 is always < 32, branch was causing shift-count-negative warning)

VERIFICATION:
-------------
- S5 Temp.Raum now correctly shows 26.1°C
- No compiler warnings
- 0% error rate maintained

FILES MODIFIED:
---------------
- src/main.c: Room sensor decoding fix, removed unused code

================================================================================
ITERATION 6 - 2026-01-23 (Architecture Analysis for Webserver Feature)
================================================================================

USER PROMPT:
------------
Analyze the current ESP32 project structure.
- Identify existing modules, headers, and configuration files
- Identify how WiFi, sensors, outputs, and MQTT are currently handled
- Identify where io_config.h, wifi_config.h, and Kconfig.projbuild are used
Do not modify code yet.
Provide: architecture overview, module boundaries, dependency diagram
Create new git branch for webserver features

BRANCH CREATED:
---------------
git checkout -b feature/webserver-config

=== PROJECT STRUCTURE ANALYSIS ===

FILES:
------
src/
├── main.c              # Main application (1253 lines)
├── mqtt_ha.c           # MQTT & WiFi implementation (816 lines)
├── mqtt_ha.h           # MQTT module header
├── io_config.h         # I/O configuration from Kconfig
├── wifi_config.h       # WiFi/MQTT credentials (git-ignored)
├── wifi_config.h.example # Template for wifi_config.h
├── Kconfig.projbuild   # ESP-IDF menuconfig definitions
└── CMakeLists.txt      # ESP-IDF build config

Root:
├── platformio.ini      # PlatformIO build configuration
├── sdkconfig.d1_mini_esp32 # ESP-IDF generated config
├── .gitignore          # Excludes wifi_config.h
└── docs/               # Protocol documentation

=== ARCHITECTURE OVERVIEW ===

The project implements a UVR1611 DL-Bus to MQTT gateway with Home Assistant
integration. It uses a pipeline architecture for signal processing on a
D1 Mini ESP32.

CURRENT DATA FLOW:
------------------
1. GPIO26 captures DL-Bus signal edges via ISR (pinned to Core 1)
2. Edge buffer (circular, 2048 entries) holds pulse durations
3. Bit Extractor task classifies pulses, extracts bits
4. Manchester Decoder task detects SYNC, assembles 64-byte frames
5. Frame queue passes valid frames to main task
6. Main task parses sensors/outputs and publishes via MQTT

CORE ALLOCATION:
----------------
- Core 0: WiFi stack, MQTT client, main task
- Core 1: GPIO ISR, Bit Extractor, Manchester Decoder (timing-critical)

=== MODULE RESPONSIBILITIES ===

1. main.c (DL-Bus Capture & Decode):
   - GPIO interrupt handler (IRAM, Core 1)
   - Edge circular buffer management
   - Bit extraction task (priority MAX-2)
   - Manchester decoder task (priority MAX-3)
   - Frame processing & parsing
   - Sensor/output/speed/heat decoding
   - Serial output
   - Statistics tracking
   - Uses: io_config.h, mqtt_ha.h

2. mqtt_ha.c (Network & MQTT):
   - NVS flash initialization
   - WiFi STA mode initialization
   - WiFi/MQTT event handling
   - MQTT client with LWT (online/offline)
   - Sensor value buffering (median calculation)
   - Output/speed state change detection
   - MQTT publishing (sensors, outputs, system)
   - Home Assistant auto-discovery
   - Publish interval management
   - Uses: wifi_config.h, io_config.h

3. io_config.h (Configuration Interface):
   - Maps Kconfig CONFIG_* values to C arrays
   - SENSOR_NAMES[], OUTPUT_NAMES[], SPEED_LEVEL_NAMES[]
   - SENSOR_UNITS[] for display formatting
   - Used by: main.c, mqtt_ha.c

4. wifi_config.h (Credentials & Settings):
   - WiFi: SSID, password, hostname, timeout
   - MQTT: broker URI, username, password, client ID
   - Topics: base topic, HA discovery prefix
   - Intervals: sensors, outputs, system, discovery
   - QoS and retain settings
   - Used by: mqtt_ha.c only

5. Kconfig.projbuild (Menuconfig):
   - Sensor names S1-S16 with help text
   - Output names A1-A13 with help text
   - Speed level names
   - Sensor unit strings by type
   - Used by: ESP-IDF build → sdkconfig → io_config.h

=== DEPENDENCY DIAGRAM (TEXTUAL) ===

                    +------------------+
                    | platformio.ini   |
                    | (build system)   |
                    +--------+---------+
                             |
                             v
+------------------+  +------+----------+  +------------------+
| Kconfig.projbuild|->| sdkconfig       |->| io_config.h      |
| (menuconfig UI)  |  | (generated)     |  | (array macros)   |
+------------------+  +-----------------+  +--------+---------+
                                                    |
                      +-----------------------------+
                      |                             |
                      v                             v
           +------------------+          +------------------+
           | wifi_config.h    |          | main.c           |
           | (credentials)    |          | - DL-Bus decode  |
           | - WiFi settings  |          | - Frame parse    |
           | - MQTT settings  |          | - Sensor arrays  |
           | - Intervals      |          +--------+---------+
           +--------+---------+                   |
                    |                             |
                    v                             v
           +------------------+          +------------------+
           | mqtt_ha.c        |<---------| (function calls) |
           | - WiFi init      |          | mqtt_ha_init()   |
           | - MQTT client    |          | mqtt_ha_start()  |
           | - HA discovery   |          | mqtt_ha_loop()   |
           | - Publishing     |          | mqtt_ha_add_*()  |
           +------------------+          +------------------+

=== RECOMMENDED MODULE BOUNDARIES FOR WEBSERVER ===

For adding webserver configuration features, recommend these new modules:

1. NEW: webserver.h / webserver.c
   - HTTP server initialization (esp_http_server)
   - Route handlers (GET/POST)
   - Static file serving (HTML/CSS/JS)
   - JSON API endpoints for config read/write
   - Live data endpoints for sensors/outputs
   - Dependencies: esp_http_server, cJSON

2. NEW: config_storage.h / config_storage.c
   - NVS-based configuration storage
   - Read/write WiFi credentials at runtime
   - Read/write MQTT settings at runtime
   - Read/write sensor/output names
   - Configuration validation
   - Dependencies: nvs_flash

3. NEW: web/ directory (embedded files)
   - index.html - Configuration UI
   - style.css - Styles
   - app.js - Client-side logic
   - Embed via CMakeLists.txt or xxd

4. MODIFY: wifi_config.h
   - Add default values for when NVS is empty
   - Support runtime override from NVS

5. MODIFY: mqtt_ha.c
   - Add functions to update settings at runtime
   - Support MQTT reconnect with new settings
   - Make intervals configurable at runtime

PROPOSED API ENDPOINTS:
-----------------------
GET  /                  -> Serve index.html
GET  /api/status        -> System status JSON (uptime, WiFi, MQTT)
GET  /api/sensors       -> Live sensor values JSON
GET  /api/outputs       -> Live output states JSON
GET  /api/config/wifi   -> WiFi settings JSON
POST /api/config/wifi   -> Update WiFi settings
GET  /api/config/mqtt   -> MQTT settings JSON
POST /api/config/mqtt   -> Update MQTT settings
GET  /api/config/io     -> Sensor/output names JSON
POST /api/config/io     -> Update sensor/output names
POST /api/reboot        -> Restart device
POST /api/factory-reset -> Clear NVS, restore defaults

PROPOSED FILE STRUCTURE AFTER WEBSERVER:
----------------------------------------
src/
├── main.c              # Unchanged (DL-Bus core)
├── mqtt_ha.c/h         # Add: runtime config update functions
├── io_config.h         # Unchanged (Kconfig defaults)
├── wifi_config.h       # Add: NVS fallback defaults
├── webserver.c/h       # NEW: HTTP server & REST API
├── config_storage.c/h  # NEW: NVS config management
├── web/
│   ├── index.html      # Configuration UI
│   ├── style.css       # Styles
│   └── app.js          # Client-side JavaScript
├── Kconfig.projbuild   # Add: webserver enable/port options
└── CMakeLists.txt      # Add: embed web files, new sources

=== CURRENT LIMITATIONS TO ADDRESS ===

1. Hardcoded credentials: wifi_config.h requires rebuild to change
2. No runtime configuration: All settings fixed at compile time
3. No web interface: Configuration requires menuconfig + rebuild
4. No OTA updates: Firmware updates require physical access
5. No captive portal: Can't configure WiFi without existing connection

================================================================================
ITERATION 7 - 2026-01-23 (Configuration Storage Abstraction)
================================================================================

USER PROMPT:
------------
Implement Task 1: Configuration Storage Abstraction
- Create central, secure configuration storage layer backed by NVS
- Separate non-secret config (safe to commit) from secret config (NVS only)
- WiFi and MQTT credentials must NEVER appear in source code, headers, Kconfig,
  sdkconfig, logs, or any committed files
- All application code must read configuration through this layer

WHAT WAS DONE:
--------------

1. Created config_store module:
   - src/config_store.h: Public API with security guarantees
   - src/config_store.c: NVS-backed implementation (~700 lines)

2. Security implementation:
   - Two NVS namespaces: "uvr_config" (settings) and "uvr_secret" (credentials)
   - Secret getters copy to caller-provided buffers (never return internal pointers)
   - Secrets cleared from memory after use (memset to 0)
   - Logging never reveals credential values ("WiFi credentials stored" not the actual SSID)

3. Configuration precedence:
   - Non-secrets: Load Kconfig default, then apply NVS override if present
   - Secrets: NVS only, NO Kconfig defaults (must be provisioned at runtime)

4. Updated Kconfig.projbuild:
   - Added Device Settings menu: hostname, GPIO, WiFi timeout
   - Added MQTT Settings menu: broker URI, client ID, topics, QoS, retain
   - Added Publish Intervals menu: sensors, outputs, system, discovery
   - Comment clearly states credentials are NOT here

5. Updated mqtt_ha.c:
   - Removed #include "wifi_config.h"
   - Added #include "config_store.h"
   - wifi_init(): Gets credentials from config_store (copy to local buffer, then clear)
   - mqtt_init(): Gets settings from config_store
   - All MQTT_* macros replaced with config_get_*() function calls
   - Credentials cleared from stack after passing to ESP-IDF APIs

6. Updated main.c:
   - Added config_store_init() call before mqtt_ha_init()
   - Added #include "config_store.h"

7. Removed obsolete files:
   - Deleted src/wifi_config.h (contained hardcoded credentials)
   - Deleted src/wifi_config.h.example (no longer needed)

8. Updated CLAUDE.md with new architecture and security model

FILES CREATED:
--------------
- src/config_store.h (300 lines): Configuration API
- src/config_store.c (700 lines): NVS implementation

FILES MODIFIED:
---------------
- src/mqtt_ha.c: Use config_store instead of wifi_config.h
- src/main.c: Initialize config_store at startup
- src/Kconfig.projbuild: Added non-secret configuration menus
- CLAUDE.md: Updated architecture documentation

FILES DELETED:
--------------
- src/wifi_config.h: Contained hardcoded credentials (security risk)
- src/wifi_config.h.example: No longer needed

=== CONFIGURATION STORAGE ARCHITECTURE ===

NVS Namespace: "uvr_config" (Non-Secrets)
-----------------------------------------
Key              | Type   | Kconfig Default
-----------------|--------|------------------
version          | u8     | CONFIG_VERSION (1)
hostname         | str    | CONFIG_UVR_HOSTNAME
mqtt_uri         | str    | CONFIG_UVR_MQTT_BROKER_URI
mqtt_client      | str    | CONFIG_UVR_MQTT_CLIENT_ID
mqtt_topic       | str    | CONFIG_UVR_MQTT_BASE_TOPIC
ha_prefix        | str    | CONFIG_UVR_HA_DISCOVERY_PREFIX
int_sensors      | u16    | CONFIG_UVR_PUBLISH_INTERVAL_SENSORS
int_outputs      | u16    | CONFIG_UVR_PUBLISH_INTERVAL_OUTPUTS
int_system       | u16    | CONFIG_UVR_PUBLISH_INTERVAL_SYSTEM
int_disc         | u16    | CONFIG_UVR_HA_DISCOVERY_INTERVAL
wifi_timeout     | u16    | CONFIG_UVR_WIFI_TIMEOUT
dlbus_gpio       | u8     | CONFIG_UVR_DLBUS_GPIO
mqtt_keep        | u16    | CONFIG_UVR_MQTT_KEEPALIVE
mqtt_qos         | u8     | CONFIG_UVR_MQTT_QOS
mqtt_ret_s       | u8     | CONFIG_UVR_MQTT_RETAIN_SENSORS
mqtt_ret_st      | u8     | CONFIG_UVR_MQTT_RETAIN_STATUS

NVS Namespace: "uvr_secret" (Credentials - NO Kconfig defaults!)
----------------------------------------------------------------
Key              | Type   | Notes
-----------------|--------|------------------
wifi_ssid        | str    | WiFi network name
wifi_pass        | str    | WiFi password
mqtt_user        | str    | MQTT username
mqtt_pass        | str    | MQTT password

=== HOW SECRETS ARE PROTECTED ===

1. No compile-time storage:
   - No #define for SSID/password anywhere
   - No Kconfig defaults for credentials
   - Not in sdkconfig or any generated files

2. Secure API design:
   - config_get_wifi_ssid(buffer, len) copies to caller buffer
   - Never returns const char* to internal storage
   - Buffer size checked, null-terminated

3. Memory hygiene:
   - After copying to ESP-IDF wifi_config_t, clear stack buffers
   - memset(pass_buf, 0, sizeof(pass_buf)) immediately after use

4. Logging safety:
   - Only log "WiFi credentials stored" not the actual values
   - Log broker URI (non-secret) but not username/password

5. Version migration:
   - Config version stored in NVS
   - On version mismatch: reset non-secrets, keep secrets

=== FIRST BOOT EXPERIENCE ===

Since credentials are no longer in source code:

1. Flash firmware
2. Device boots, config_store_init() runs
3. Logs: "WiFi credentials: NOT configured"
4. mqtt_ha_init() fails with ESP_ERR_NOT_FOUND
5. DL-Bus reading continues (local serial output)
6. User must provision credentials via:
   - Future: Web interface / captive portal
   - Future: Serial console tool
   - Direct: esptool.py NVS write

NEXT STEPS:
-----------
1. Implement webserver for credential provisioning
2. Add captive portal mode when WiFi not configured
3. Add serial console provisioning commands
4. Test version migration on firmware updates

================================================================================
ITERATION 8 - 2026-01-24 (Web Configuration & WiFi STA/AP Mode)
================================================================================

USER PROMPT:
------------
Implement web-based configuration interface with WiFi AP mode fallback for
initial device setup.

WHAT WAS DONE:
--------------

1. Created WiFi Manager Module:
   - src/wifi_manager.h: Public API for WiFi management
   - src/wifi_manager.c: Implementation with STA/AP mode switching

   WiFi Manager Features:
   - Attempts STA mode connection on boot with stored credentials
   - Falls back to AP mode if no credentials or connection fails
   - AP mode SSID: "UVR1611-XXXXXX" (XXXXXX = last 6 chars of MAC)
   - AP mode IP: 192.168.4.1
   - mDNS support for hostname.local access
   - Reconnection support after saving new credentials

2. Created Webserver Module:
   - src/webserver.h: Public API for HTTP server
   - src/webserver.c: Implementation with embedded HTML UI

   Webserver Features:
   - Built-in HTML/CSS configuration interface
   - Status page with live sensor/output data
   - WiFi configuration form
   - MQTT configuration form
   - REST API endpoints for JSON data
   - Works in both STA and AP modes

   Endpoints:
   - GET /          -> Main status page (HTML)
   - GET /api/status -> System status JSON
   - GET /api/sensors -> Live sensor values JSON
   - GET /api/outputs -> Output states JSON
   - POST /api/config/wifi -> Save WiFi settings
   - POST /api/config/mqtt -> Save MQTT settings
   - POST /api/reboot -> Restart device

3. Fixed Kconfig bool handling:
   - MQTT retain options were not working correctly
   - Fixed bool to int conversion in config_store.c

4. Updated main.c:
   - Integrated wifi_manager and webserver initialization
   - DL-Bus reading continues regardless of WiFi mode
   - MQTT only starts when in STA mode with connection

ARCHITECTURE CHANGES:
---------------------

Before (Iteration 7):
  app_main() -> mqtt_ha_init() -> WiFi STA only -> MQTT

After (Iteration 8):
  app_main() -> wifi_manager_init() -> wifi_manager_start()
             -> webserver_start()
             |
             +-> If STA connected: mqtt_ha_init() -> MQTT publishing
             +-> If AP mode: Web UI only, no MQTT

NEW FILES:
----------
- src/wifi_manager.h: WiFi manager API
- src/wifi_manager.c: WiFi STA/AP management (~400 lines)
- src/webserver.h: Webserver API
- src/webserver.c: HTTP server with embedded UI (~800 lines)

MODIFIED FILES:
---------------
- src/main.c: Integrated new modules
- src/config_store.c: Fixed bool handling for retain options
- src/Kconfig.projbuild: Fixed bool defaults

FIRST BOOT EXPERIENCE (FINAL):
------------------------------
1. Flash firmware to ESP32
2. Device boots, no credentials -> starts AP mode
3. Serial log shows: "Starting AP mode: UVR1611-XXXXXX"
4. User connects phone/laptop to "UVR1611-XXXXXX" network
5. Open http://192.168.4.1 in browser
6. Configure WiFi SSID, password, MQTT broker, etc.
7. Click Save -> device stores settings in NVS
8. Device reboots, connects to configured WiFi (STA mode)
9. MQTT publishing starts, Home Assistant discovers entities
10. Web UI accessible at http://hostname.local or device IP

PHASE 3 STATUS: COMPLETE
------------------------
All webserver configuration features implemented:
- [x] HTTP server for settings UI
- [x] NVS-based runtime configuration
- [x] REST API for config read/write
- [x] Live sensor/output data display
- [x] WiFi STA/AP mode with auto-fallback
- [x] mDNS hostname resolution

MERGED TO MAIN:
---------------
Pull request #1 (feature/webserver-config) merged to main.

================================================================================
ITERATION 9 - 2026-01-24 (Bug Fixes & New Features)
================================================================================

USER PROMPTS:
-------------
1. "heat_meter power and energy are updating every frame and not with the set interval"
2. "I also want to edit Sensor and output names via webserver"
3. "if there is enough memory left add OTA firmware update"
4. "system parameters like mac and uptime should also publish with standard interval"
5. "hostname should also be the name in mqtt publish and homeassistant discovery"

WHAT WAS DONE:
--------------

1. HEAT METER INTERVAL FIX:
   - Heat meters were publishing every DL-Bus frame instead of using interval
   - Added heat_meter_buffer_t for buffering power/energy samples
   - Replaced mqtt_ha_publish_heat_meter() with mqtt_ha_add_heat_meter_sample()
   - Added mqtt_ha_publish_heat_meters() that calculates median
   - Heat meters now publish on sensor interval (default 30s)

2. I/O NAMES VIA WEB UI:
   - Added sensor_names[16] and output_names[13] to config_store
   - Added config_get_sensor_name(), config_set_sensor_name()
   - Added config_get_output_name(), config_set_output_name()
   - Names stored in NVS with Kconfig fallback
   - Added I/O Names section to /config page (forms for S1-S16, A1-A13)
   - Added POST /config/io endpoint
   - Updated mqtt_ha.c, main.c, webserver.c to use config functions

3. OTA FIRMWARE UPDATE:
   - Created partitions.csv with OTA-compatible layout (two 1.75MB partitions)
   - Updated platformio.ini to use custom partition table
   - Added OTA update section to /config page with:
     - Current firmware version and build date display
     - File picker for .bin firmware files
     - JavaScript upload with progress indicator
   - Added POST /ota endpoint with:
     - Firmware header validation
     - 4KB chunk writing to flash
     - Auto-reboot on success

4. SYSTEM INFO INTERVAL FIX:
   - System info (MAC, IP, uptime) was on separate interval
   - Now publishes together with sensors on sensor_interval
   - Removed last_system_publish variable

5. HOSTNAME IN HOME ASSISTANT:
   - Device name in HA discovery was hardcoded "UVR1611 Gateway"
   - Now uses config_get_hostname() for device name
   - Updated publish_ha_sensor_discovery()
   - Updated publish_ha_binary_sensor_discovery()
   - Renamed "UVR1611 Uptime" to just "Uptime"

NEW/MODIFIED FILES:
-------------------
- partitions.csv: New OTA partition table
- platformio.ini: Added board_build.partitions
- src/config_store.h: Added I/O name functions
- src/config_store.c: Implemented I/O name storage
- src/mqtt_ha.c: Heat meter buffering, hostname in discovery, interval fixes
- src/mqtt_ha.h: New heat meter API
- src/webserver.c: I/O names form, OTA update handler
- src/main.c: Use config functions for I/O names

BUILD RESULT:
-------------
RAM:   15.7% (51408 / 327680 bytes)
Flash: 97.3% (1019893 / 1048576 bytes) - before OTA partition change

With OTA partitions: ~1.75MB available per partition (plenty of room)

================================================================================
ITERATION 10 - 2026-01-24 (Home Assistant Diagnostic Entities)
================================================================================

USER PROMPT:
------------
"the status, IP address and MAC address are missing in the homeassistant mqtt
autodiscovery"

PROBLEM:
--------
While the device was publishing status, IP, and MAC to MQTT topics, these values
were not appearing in Home Assistant because they lacked autodiscovery
configuration messages.

WHAT WAS DONE:
--------------

1. Added Home Assistant autodiscovery for three new diagnostic entities:

   a) IP Address Sensor:
      - Discovery topic: homeassistant/sensor/{device_id}/system_ip/config
      - State topic: {base_topic}/system/ip
      - entity_category: diagnostic
      - icon: mdi:ip-network

   b) MAC Address Sensor:
      - Discovery topic: homeassistant/sensor/{device_id}/system_mac/config
      - State topic: {base_topic}/system/mac
      - entity_category: diagnostic
      - icon: mdi:network-outline

   c) Connectivity Status Binary Sensor:
      - Discovery topic: homeassistant/binary_sensor/{device_id}/system_status/config
      - State topic: {base_topic}/status
      - device_class: connectivity
      - entity_category: diagnostic
      - payload_on: "online"
      - payload_off: "offline"

2. Fixed IP address not being published:
   - Added #include "wifi_manager.h" to mqtt_ha.c
   - Call wifi_manager_get_ip() before publishing IP address
   - Also updated mqtt_ha_get_system_info() for webserver display

FILES MODIFIED:
---------------
- src/mqtt_ha.c: Added autodiscovery for diagnostic entities, fixed IP publishing
- CLAUDE.md: Added Home Assistant auto-discovery documentation
- README.md: Added PCB folder mention and diagnostic entities
- prompt_history.txt: This update

RESULT:
-------
All three diagnostic entities now appear in Home Assistant under the device:
- IP Address (diagnostic section)
- MAC Address (diagnostic section)
- Status (connectivity, diagnostic section)

================================================================================
ITERATION 12 - 2026-01-25 (Save & Reboot Button Bug Fix)
================================================================================

USER PROMPT:
------------
"button save&reboot seems only to reboot without saving settings before"

PROBLEM:
--------
On the I/O Names configuration page (/config/io-names), the "Save & Reboot" button
was not saving the form data before rebooting. Users would lose their changes.

ROOT CAUSE:
-----------
In webserver.c config_io_names_handler(), the "Save & Reboot" button was in a
separate HTML <form> that only posted to /reboot:

    <button type="submit">Save I/O Names</button>
    </form>
    <form method="POST" action="/reboot">
    <button type="submit" class="danger">Save &amp; Reboot</button>
    </form>

The "Save I/O Names" button correctly submitted to /config/io, but the
"Save & Reboot" button was in its own form that skipped the save entirely.

FIX APPLIED:
------------
Changed the "Save & Reboot" button to use JavaScript that:
1. Collects form data from the I/O names form
2. Submits it via AJAX to /config/io
3. On success, sends a POST to /reboot
4. On failure, shows an alert to the user

New implementation:
- Button is now type="button" with onclick="saveAndReboot()"
- JavaScript function uses FormData and XMLHttpRequest
- Sequential requests ensure save completes before reboot
- Error handling for both save and reboot failures

FILES MODIFIED:
---------------
- src/webserver.c: Fixed Save & Reboot button implementation

RESULT:
-------
The "Save & Reboot" button now correctly saves all I/O name settings to NVS
before triggering the device reboot.

================================================================================
ITERATION 11 - 2026-01-25 (Configurable Speed & Heat Meter Names, Name Filtering)
================================================================================

USER PROMPT:
------------
"Make speed level names (Drehzahlstufen), heat meter energy names, and heat meter
power names configurable via the webserver. Only add Sensors/Outputs/Drehzahlstufen/
Heat meter energy and heat meter power to Home Assistant MQTT discovery if a name
is configured. Exclude names with only '-' without numbers and letters. Also only
publish values with configured names."

WHAT WAS DONE:
--------------

1. CONFIGURATION STORAGE (config_store.h/c):
   - Added constants: CONFIG_NUM_SPEED_LEVELS (4), CONFIG_NUM_HEAT_METERS (2)
   - Added NVS storage for speed level names (4) and heat meter names (2 power + 2 energy)
   - Added getter/setter functions:
     * config_get_speed_name() / config_set_speed_name()
     * config_get_heat_meter_power_name() / config_set_heat_meter_power_name()
     * config_get_heat_meter_energy_name() / config_set_heat_meter_energy_name()
   - Added config_is_name_enabled() helper function:
     * Returns true only if name contains at least one alphanumeric character
     * Returns false for NULL, empty, or only-dashes names like "---"

2. KCONFIG DEFAULTS (Kconfig.projbuild):
   - Added "Heat Meter Names" menu with configurable defaults:
     * HEAT_METER_1_POWER_NAME: "WMZ1 Leistung"
     * HEAT_METER_1_ENERGY_NAME: "WMZ1 Energie"
     * HEAT_METER_2_POWER_NAME: "WMZ2 Leistung"
     * HEAT_METER_2_ENERGY_NAME: "WMZ2 Energie"

3. I/O CONFIG (io_config.h):
   - Added NUM_HEAT_METERS constant
   - Added HEAT_METER_POWER_NAMES and HEAT_METER_ENERGY_NAMES macros

4. WEB UI (webserver.c):
   - Added form section for 4 speed level names (Drehzahlstufen A1, A2, A6, A7)
   - Added form section for 4 heat meter names (WMZ1/WMZ2 power and energy)
   - Updated form handler (config_io_handler) to process and save all new fields
   - Increased form buffer size from 2048 to 4096 bytes

5. MQTT PUBLISHING (mqtt_ha.c):
   - All entity types now use config_is_name_enabled() to filter publishing:
     * mqtt_ha_publish_sensors() - skip sensors without valid names
     * mqtt_ha_publish_outputs() - skip outputs without valid names
     * mqtt_ha_publish_speeds() - skip speed levels without valid names
     * mqtt_ha_publish_heat_meters() - skip heat meters without valid names
   - Immediate-on-change publishing also respects name filtering:
     * mqtt_ha_update_output() - checks name before publishing
     * mqtt_ha_update_speed() - checks name before publishing
   - Heat meters now use configurable names instead of hardcoded "Heat Meter X"
   - Speed levels now use config_get_speed_name() instead of static array

6. HOME ASSISTANT DISCOVERY (mqtt_ha.c):
   - mqtt_ha_publish_discovery() updated to filter all entity types:
     * Only registers sensors with enabled names
     * Only registers outputs with enabled names
     * Only registers speed levels with enabled names
     * Only registers heat meters with enabled names
   - Uses configurable names for speed levels and heat meters

7. DOCUMENTATION:
   - Updated CLAUDE.md with new APIs and features
   - Updated README.md with detailed configuration instructions

NAME FILTERING LOGIC:
---------------------
Names are DISABLED (not published/discovered) if:
- NULL or empty string
- Contains only "-" characters (like "---")
- Contains no letters (A-Z, a-z) and no digits (0-9)

Example:
| Name | config_is_name_enabled() | Published? |
|---|---|---|
| "T.Heizkr.VL" | true | Yes |
| "WMZ1 Leistung" | true | Yes |
| "---" | false | No |
| "" | false | No |
| "- - -" | false | No |

FILES CREATED:
--------------
None (all features added to existing files)

FILES MODIFIED:
---------------
- src/config_store.h: Added speed/heat meter name APIs, config_is_name_enabled()
- src/config_store.c: Implemented storage and getter/setters (~150 lines added)
- src/io_config.h: Added NUM_HEAT_METERS, heat meter name macros
- src/Kconfig.projbuild: Added Heat Meter Names menu
- src/webserver.c: Added speed/heat meter name forms (~80 lines added)
- src/mqtt_ha.c: Name filtering for all publishing and discovery functions
- CLAUDE.md: Updated configuration documentation
- README.md: Added detailed I/O configuration section

RESULT:
-------
- Speed level names are now editable via web UI
- Heat meter power/energy names are now editable via web UI
- Entities with "---" or empty names are not published to MQTT
- Entities with "---" or empty names do not appear in Home Assistant
- Users can selectively disable unused sensors/outputs/speed levels/heat meters

================================================================================

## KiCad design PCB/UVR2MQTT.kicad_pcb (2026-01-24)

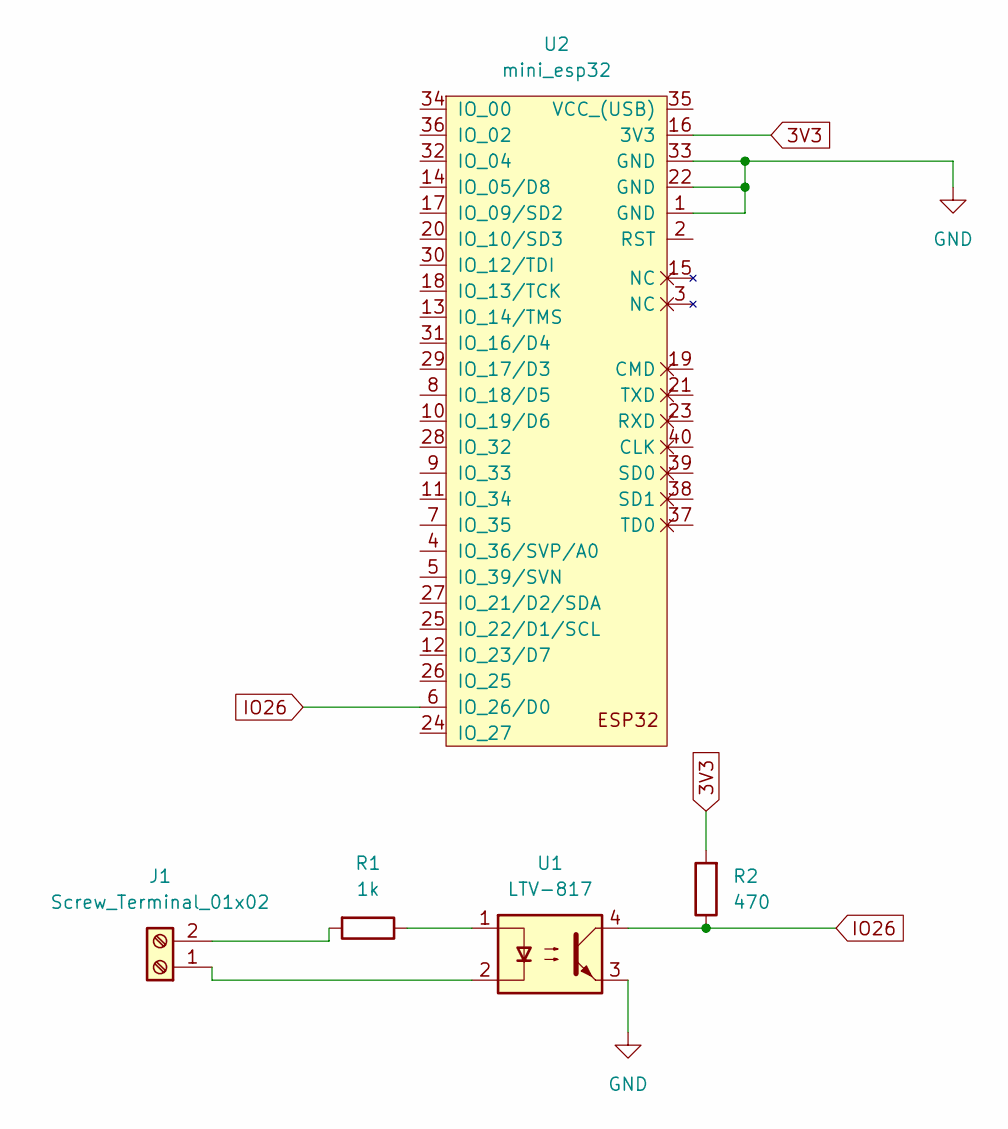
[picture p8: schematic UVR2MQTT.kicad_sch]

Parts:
J1: Screw_Terminal_01x02
R1: 1k; R_Axial_DIN0207_L6.3mm_D2.5mm_P10.16mm_Horizontal
R2: 470; R_Axial_DIN0207_L6.3mm_D2.5mm_P10.16mm_Horizontal
U1: LTV-817; DIP-4_W7.62mm
U2: mini_esp32; ESP32_mini

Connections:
3V3: R2.2, U2.16 (3V3)
GND: U1.3, U2.1 (GND), U2.22 (GND), U2.33 (GND)
IO26: R2.1, U1.4, U2.6 (IO_26/D0)
unnamed: J1.1, U1.2
unnamed: J1.2, R1.2
unnamed: R1.1, U1.1

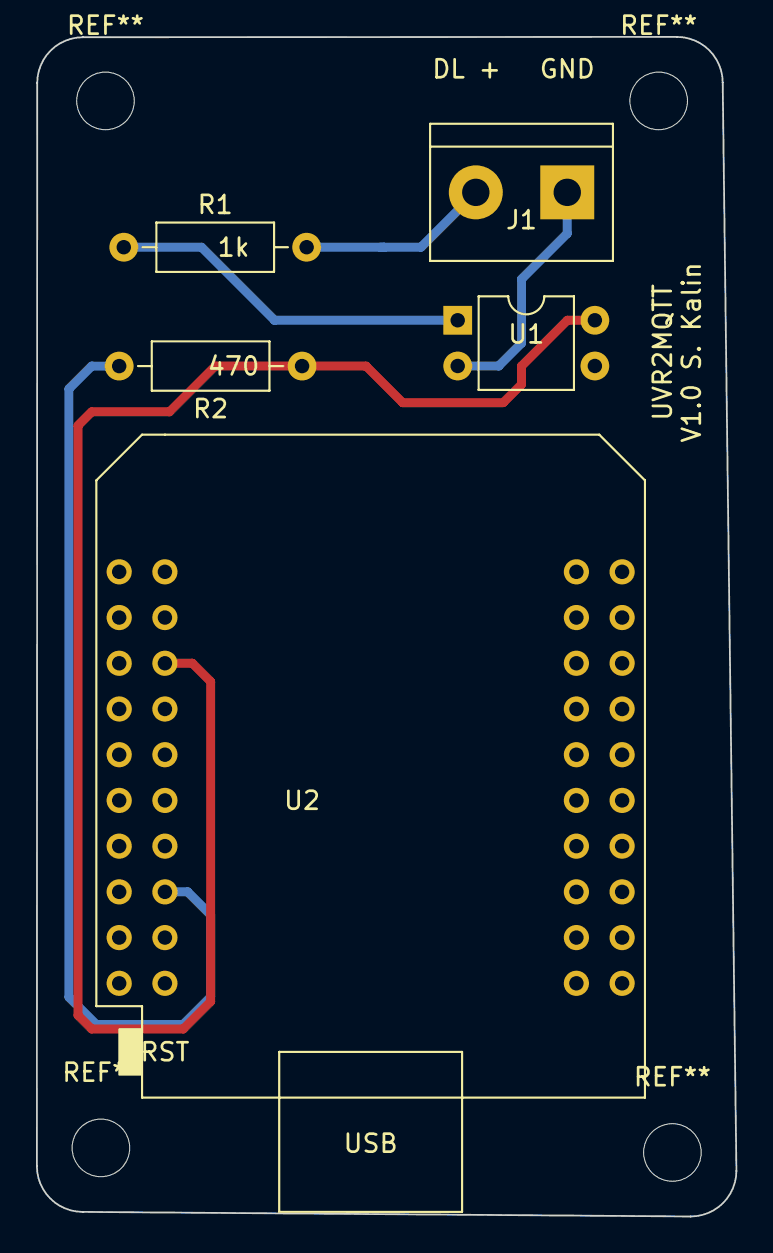
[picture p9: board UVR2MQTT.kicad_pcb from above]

Board: 2 copper layers, 38.9 x 65.5 mm, 5 parts (0 on the bottom side), 6 nets.

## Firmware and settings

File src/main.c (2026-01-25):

/**
 * UVR1611 DL-Bus Reader - Phase 1: Pipeline Architecture
 *
 * Architecture:
 *   GPIO Interrupt -> Edge Circular Buffer -> Bit Extractor Task
 *                  -> Manchester Decoder Task -> Frame Queue
 *
 * Using GPIO interrupts instead of RMT to avoid buffer size limitations.
 * ESP32 RMT without DMA is limited to 512 symbols, but we need ~656.
 *
 * DL-Bus Protocol (UVR1611):
 * - Display clock: 488 Hz
 * - Bit duration: 2.048 ms (2048 us)
 * - Half-bit duration: 1.024 ms (1024 us)
 * - Data is XOR'd with 488 Hz clock, then inverted by output transistor
 * - SYNC: 16 high bits without start/stop bit
 * - Byte format: 1 start bit (0), 8 data bits (LSB first), 1 stop bit (1)
 * - Frame: SYNC + 64 bytes (device ID, data, checksum)
 *
 * Hardware: Azdelivery D1 Mini ESP32, GPIO26 for DL-Bus input
 */

#include <stdio.h>
#include <string.h>
#include "freertos/FreeRTOS.h"
#include "freertos/task.h"
#include "freertos/queue.h"
#include "freertos/semphr.h"
#include "driver/gpio.h"
#include "esp_intr_alloc.h"
#include "esp_log.h"
#include "esp_timer.h"
#include "esp_rom_sys.h"
#include "soc/gpio_struct.h"
#include "io_config.h"
#include "config_store.h"
#include "mqtt_ha.h"
#include "wifi_manager.h"
#include "webserver.h"

static const char *TAG = "DL-BUS";

// =============================================================================
// I/O Configuration Arrays (from Kconfig, speed/units not editable via web)
// =============================================================================
static const char *speed_level_names[NUM_SPEED_LEVELS] = SPEED_LEVEL_NAMES;
static const char *sensor_units[NUM_SENSOR_TYPES] = SENSOR_UNITS;

// =============================================================================
// Frame Byte Offsets (UVR1611 Protocol)
// =============================================================================
#define FRAME_OFF_DEVICE_ID     0
#define FRAME_OFF_DEVICE_ID_INV 1
#define FRAME_OFF_RESERVED      2
#define FRAME_OFF_MINUTE        3
#define FRAME_OFF_HOUR          4
#define FRAME_OFF_DAY           5
#define FRAME_OFF_MONTH         6
#define FRAME_OFF_YEAR          7
#define FRAME_OFF_SENSORS       8   // 16 sensors × 2 bytes = bytes 8-39
#define FRAME_OFF_OUTPUTS_1     40  // Outputs A1-A8
#define FRAME_OFF_OUTPUTS_2     41  // Outputs A9-A13
#define FRAME_OFF_SPEED_A1      42
#define FRAME_OFF_SPEED_A2      43
#define FRAME_OFF_SPEED_A6      44
#define FRAME_OFF_SPEED_A7      45
#define FRAME_OFF_HEAT_REG      46  // Heat meter register
#define FRAME_OFF_HEAT1         47  // Heat meter 1 (8 bytes)
#define FRAME_OFF_HEAT2         55  // Heat meter 2 (8 bytes)
#define FRAME_OFF_CHECKSUM      63

// Sensor type codes (upper nibble of high byte)
#define SENSOR_TYPE_UNUSED      0x00
#define SENSOR_TYPE_DIGITAL     0x10
#define SENSOR_TYPE_TEMP        0x20
#define SENSOR_TYPE_FLOW        0x30
#define SENSOR_TYPE_RADIATION   0x60
#define SENSOR_TYPE_ROOM        0x70

// =============================================================================
// Hardware Configuration
// =============================================================================
#define DL_BUS_GPIO         GPIO_NUM_26

// =============================================================================
// DL-Bus Timing Constants (in microseconds)
// =============================================================================
#define BIT_DURATION_US     2048        // One bit = 2.048 ms
#define HALF_BIT_US         1024        // Half bit = 1.024 ms
#define TOLERANCE_US        350         // Timing tolerance (increased for WiFi interference)

// Pulse classification thresholds
// With 350us tolerance: SHORT=674-1374us, LONG=1698-2398us, gap=1374-1698us
#define SHORT_PULSE_MIN     (HALF_BIT_US - TOLERANCE_US)    // ~674 us
#define SHORT_PULSE_MAX     (HALF_BIT_US + TOLERANCE_US)    // ~1374 us
#define LONG_PULSE_MIN      (BIT_DURATION_US - TOLERANCE_US) // ~1698 us
#define LONG_PULSE_MAX      (BIT_DURATION_US + TOLERANCE_US) // ~2398 us
#define PULSE_MIDPOINT      ((SHORT_PULSE_MAX + LONG_PULSE_MIN) / 2) // ~1536 us

// =============================================================================
// Frame Configuration
// =============================================================================
#define SYNC_BITS           16          // SYNC = 16 high bits
#define SYNC_HALF_BITS      32          // = 32 half-bit periods
#define FRAME_BYTES         64          // 64 data bytes after SYNC
#define BITS_PER_BYTE       10          // 1 start + 8 data + 1 stop

// =============================================================================
// Buffer Sizes
// =============================================================================
// Frame = SYNC(16 bits) + 64 bytes × 10 bits = 656 bits × ~2 pulses/bit = ~1312 pulses
// 1.5 frames = ~2000 pulses, use 2048 for circular buffer
#define EDGE_BUFFER_SIZE    2048

// Bit queue: 64 bytes x 10 bits = 640 bits/frame, use 1024 for margin
#define BIT_QUEUE_SIZE      1024

// Frame queue: hold 2-3 complete frames
#define FRAME_QUEUE_SIZE    3

// =============================================================================
// Data Types
// =============================================================================

// Pulse classification
typedef enum {
    PULSE_SHORT,        // Half-bit pulse (~1024 us)
    PULSE_LONG,         // Full-bit pulse (~2048 us)
    PULSE_INVALID       // Out of expected range
} pulse_type_t;

// Edge entry in circular buffer
typedef struct {
    uint16_t duration;  // Pulse duration in us
    uint8_t level;      // 0 = low, 1 = high
} edge_t;

// Circular buffer for edges
typedef struct {
    edge_t buffer[EDGE_BUFFER_SIZE];
    volatile uint32_t head;         // Write position (producer)
    volatile uint32_t tail;         // Read position (consumer)
    SemaphoreHandle_t mutex;        // Protect concurrent access
    SemaphoreHandle_t data_ready;   // Signal data available
} edge_buffer_t;

// Bit entry for queue
typedef struct {
    uint8_t value;      // 0 or 1
    uint8_t is_sync;    // 1 if this bit is part of SYNC marker
} bit_entry_t;

// Complete decoded frame
typedef struct {
    uint8_t data[FRAME_BYTES];
    uint8_t length;
    uint8_t valid;      // Checksum OK
    uint32_t timestamp; // Tick count when received
} dlbus_frame_t;

// =============================================================================
// Global Variables
// =============================================================================

// GPIO interrupt capture state
static volatile int64_t last_edge_time = 0;
static volatile int last_level = -1;

// Pipeline buffers/queues
static edge_buffer_t edge_buffer;
static QueueHandle_t bit_queue;
static QueueHandle_t frame_queue;

// Task handles
static TaskHandle_t bit_extractor_task_handle = NULL;
static TaskHandle_t manchester_decoder_task_handle = NULL;

// Statistics
static volatile uint32_t stat_edges_received = 0;
static volatile uint32_t stat_bits_extracted = 0;
static volatile uint32_t stat_syncs_detected = 0;
static volatile uint32_t stat_frames_decoded = 0;
static volatile uint32_t stat_frames_valid = 0;
static volatile uint32_t stat_errors = 0;
static volatile uint32_t stat_gaps_detected = 0;
static volatile uint32_t stat_short_pulses = 0;
static volatile uint32_t stat_long_pulses = 0;
static volatile uint32_t stat_invalid_pulses = 0;
static volatile uint32_t stat_midgap_pulses = 0;  // Pulses classified by proximity (WiFi jitter)

// Debug: last frame bit count
static volatile uint32_t debug_last_frame_bits = 0;
static volatile uint32_t debug_bits_since_sync = 0;

// =============================================================================
// Edge Circular Buffer Functions
// =============================================================================

static void edge_buffer_init(edge_buffer_t *eb)
{
    memset(eb->buffer, 0, sizeof(eb->buffer));
    eb->head = 0;
    eb->tail = 0;
    eb->mutex = xSemaphoreCreateMutex();
    eb->data_ready = xSemaphoreCreateBinary();
}

static inline uint32_t edge_buffer_count(edge_buffer_t *eb)
{
    uint32_t head = eb->head;
    uint32_t tail = eb->tail;
    if (head >= tail) {
        return head - tail;
    }
    return EDGE_BUFFER_SIZE - tail + head;
}

static inline bool edge_buffer_is_full(edge_buffer_t *eb)
{
    return edge_buffer_count(eb) >= (EDGE_BUFFER_SIZE - 1);
}

static inline bool edge_buffer_is_empty(edge_buffer_t *eb)
{
    return eb->head == eb->tail;
}

// Get edge from buffer (consumer side)
static bool edge_buffer_get(edge_buffer_t *eb, edge_t *edge)
{
    if (edge_buffer_is_empty(eb)) {
        return false;
    }

    *edge = eb->buffer[eb->tail];
    eb->tail = (eb->tail + 1) % EDGE_BUFFER_SIZE;

    return true;
}


// =============================================================================
// Pulse Classification
// =============================================================================

static pulse_type_t classify_pulse(uint32_t duration_us)
{
    if (duration_us >= SHORT_PULSE_MIN && duration_us <= SHORT_PULSE_MAX) {
        return PULSE_SHORT;
    } else if (duration_us >= LONG_PULSE_MIN && duration_us <= LONG_PULSE_MAX) {
        return PULSE_LONG;
    } else if (duration_us > SHORT_PULSE_MAX && duration_us < LONG_PULSE_MIN) {
        // Pulse in the gap between short and long - classify by proximity
        // This handles WiFi-induced timing jitter
        stat_midgap_pulses++;
        return (duration_us < PULSE_MIDPOINT) ? PULSE_SHORT : PULSE_LONG;
    }
    return PULSE_INVALID;
}

// =============================================================================
// GPIO Interrupt Handler
// =============================================================================

/**
 * GPIO ISR - captures edge timestamps for DL-Bus decoding
 *
 * Optimized for minimal latency:
 * - No semaphore signaling (task polls instead)
 * - Inline buffer write
 * - Minimal branching
 */
static void IRAM_ATTR gpio_isr_handler(void *arg)
{
    int64_t now = esp_timer_get_time();
    // Use direct register read instead of gpio_get_level() - IRAM safe
    // gpio_get_level() accesses flash and causes cache errors during NVS/WiFi init
    int level = (GPIO.in >> DL_BUS_GPIO) & 1;
    int64_t prev = last_edge_time;

    last_edge_time = now;

    if (prev > 0) {
        uint32_t duration = (uint32_t)(now - prev);

        // Filter: valid pulses are 500-10000us (more tolerant range)
        if (duration >= 500 && duration <= 10000) {
            // Inline buffer write for speed
            uint32_t head = edge_buffer.head;
            uint32_t next = (head + 1) % EDGE_BUFFER_SIZE;
            if (next != edge_buffer.tail) {  // Not full
                edge_buffer.buffer[head].duration = (uint16_t)duration;
                edge_buffer.buffer[head].level = !level;  // Level that just ended
                edge_buffer.head = next;
                stat_edges_received++;
            }
        }
    }
}

// Interrupt handle for dedicated GPIO interrupt
static intr_handle_t gpio_intr_handle = NULL;

/**
 * Dedicated GPIO ISR - handles the raw GPIO interrupt directly
 * This bypasses the gpio_isr_service dispatcher for lower latency
 */
static void IRAM_ATTR gpio_dedicated_isr(void *arg)
{
    // Clear the interrupt status for our GPIO
#if DL_BUS_GPIO < 32
    GPIO.status_w1tc = (1ULL << DL_BUS_GPIO);
#else
    GPIO.status1_w1tc.val = (1ULL << (DL_BUS_GPIO - 32));
#endif

    // Call our handler
    gpio_isr_handler(arg);
}

/**
 * Initialize GPIO interrupt for DL-Bus capture
 * Uses dedicated interrupt (not shared ISR service) for lower latency
 * ISR is pinned to Core 1 to avoid WiFi interference (WiFi runs on Core 0)
 */
static esp_err_t init_gpio_capture(void)
{
    ESP_LOGI(TAG, "Initializing GPIO interrupt capture on GPIO%d (Core 1)", DL_BUS_GPIO);

    // Configure GPIO for input with interrupt
    gpio_config_t io_conf = {
        .pin_bit_mask = (1ULL << DL_BUS_GPIO),
        .mode = GPIO_MODE_INPUT,
        .pull_up_en = GPIO_PULLUP_ENABLE,
        .pull_down_en = GPIO_PULLDOWN_DISABLE,
        .intr_type = GPIO_INTR_ANYEDGE,  // Trigger on both rising and falling edges
    };
    ESP_ERROR_CHECK(gpio_config(&io_conf));

    // Allocate dedicated interrupt on Core 1 with high priority
    // ESP_INTR_FLAG_IRAM: ISR in IRAM for fast execution during flash operations
    // ESP_INTR_FLAG_LEVEL3: High priority (level 4+ requires assembly handlers)
    // Pinned to Core 1 via xTaskCreatePinnedToCore context (called from Core 1 task)
    int intr_flags = ESP_INTR_FLAG_IRAM | ESP_INTR_FLAG_LEVEL3;

    esp_err_t ret = esp_intr_alloc(ETS_GPIO_INTR_SOURCE, intr_flags,
                                   gpio_dedicated_isr, NULL, &gpio_intr_handle);
    if (ret != ESP_OK) {
        ESP_LOGE(TAG, "Failed to allocate GPIO interrupt: %s", esp_err_to_name(ret));
        return ret;
    }

    // Enable interrupt for our GPIO pin
    ESP_ERROR_CHECK(gpio_intr_enable(DL_BUS_GPIO));

    // Initialize timing
    last_edge_time = 0;
    last_level = (GPIO.in >> DL_BUS_GPIO) & 1;

    ESP_LOGI(TAG, "GPIO dedicated interrupt capture initialized");
    return ESP_OK;
}

// =============================================================================
// Bit Extractor Task
// =============================================================================
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
void app_main(void)
{
    printf("\n\n");
    printf("================================================\n");
    printf("  UVR1611 DL-Bus Reader - MQTT Gateway\n");
    printf("================================================\n");
    printf("GPIO:         %d\n", DL_BUS_GPIO);
    printf("Bit duration: %d us (488 Hz clock)\n", BIT_DURATION_US);
    printf("Frame size:   %d bytes\n", FRAME_BYTES);
    printf("================================================\n\n");

    // ==========================================================================
    // Initialize DL-Bus Capture FIRST (before WiFi to avoid timing interference)
    // ==========================================================================

    // Check signal activity before setting up interrupts
    init_gpio_for_debug();
    printf("Checking signal activity...\n");
    debug_gpio_activity(500);

    // Initialize circular buffer
    ESP_LOGI(TAG, "Initializing edge buffer (size=%d)", EDGE_BUFFER_SIZE);
    edge_buffer_init(&edge_buffer);

    // Create queues
    ESP_LOGI(TAG, "Creating bit queue (size=%d)", BIT_QUEUE_SIZE);
    bit_queue = xQueueCreate(BIT_QUEUE_SIZE, sizeof(bit_entry_t));
    if (bit_queue == NULL) {
        ESP_LOGE(TAG, "Failed to create bit queue");
        return;
    }

    ESP_LOGI(TAG, "Creating frame queue (size=%d)", FRAME_QUEUE_SIZE);
    frame_queue = xQueueCreate(FRAME_QUEUE_SIZE, sizeof(dlbus_frame_t));
    if (frame_queue == NULL) {
        ESP_LOGE(TAG, "Failed to create frame queue");
        return;
    }

    // Initialize GPIO interrupt on Core 1 (away from WiFi on Core 0)
    // This requires running init code on Core 1 since esp_intr_alloc pins to current core
    core1_init_done = xSemaphoreCreateBinary();
    xTaskCreatePinnedToCore(core1_init_task, "core1_init", 2048, NULL,
                            configMAX_PRIORITIES - 1, NULL, 1);
    xSemaphoreTake(core1_init_done, portMAX_DELAY);
    vSemaphoreDelete(core1_init_done);
    ESP_ERROR_CHECK(core1_init_result);

    // Create DL-Bus tasks PINNED TO CORE 1 (WiFi runs on Core 0)
    // This prevents WiFi interrupts from interfering with timing-critical DL-Bus decoding
    ESP_LOGI(TAG, "Starting pipeline tasks on Core 1...");

    // Bit extractor task - high priority, pinned to Core 1
    xTaskCreatePinnedToCore(bit_extractor_task, "bit_extract", 4096, NULL,
                            configMAX_PRIORITIES - 2, &bit_extractor_task_handle, 1);

    // Manchester decoder task - medium-high priority, pinned to Core 1
    xTaskCreatePinnedToCore(manchester_decoder_task, "manchester", 4096, NULL,
                            configMAX_PRIORITIES - 3, &manchester_decoder_task_handle, 1);

    ESP_LOGI(TAG, "DL-Bus pipeline started on Core 1!");

    // Wait for DL-Bus pipeline to stabilize before starting WiFi
    // WiFi initialization causes significant interrupt activity
    vTaskDelay(pdMS_TO_TICKS(2000));
    ESP_LOGI(TAG, "DL-Bus pipeline stabilized");

    // ==========================================================================
    // Initialize Configuration Store (NVS)
    // ==========================================================================
    ESP_LOGI(TAG, "Initializing configuration store...");
    if (config_store_init() != ESP_OK) {
        ESP_LOGE(TAG, "Config store initialization failed!");
        // Continue - DL-Bus reading will still work but no MQTT
    }

    // ==========================================================================
    // Initialize WiFi Manager (handles STA/AP mode switching)
    // ==========================================================================
    ESP_LOGI(TAG, "Initializing WiFi Manager...");
    if (wifi_manager_init() != ESP_OK) {
        ESP_LOGE(TAG, "WiFi Manager initialization failed!");
    } else {
        ESP_LOGI(TAG, "Starting WiFi (STA mode or AP fallback)...");
        wifi_manager_start();  // Connects to WiFi or starts AP mode

        char ip[16], mac[18];
        wifi_manager_get_ip(ip, sizeof(ip));
        wifi_manager_get_mac(mac, sizeof(mac));

        if (wifi_manager_is_ap_mode()) {
            char ap_ssid[32];
            wifi_manager_get_ap_ssid(ap_ssid, sizeof(ap_ssid));
            ESP_LOGW(TAG, "Started in AP mode: SSID=%s, IP=%s", ap_ssid, ip);
        } else {
            ESP_LOGI(TAG, "WiFi connected: IP=%s, MAC=%s", ip, mac);
        }
    }

    // ==========================================================================
    // Start Web Server (works in both STA and AP modes)
    // ==========================================================================
    ESP_LOGI(TAG, "Starting web server...");
    if (webserver_start() != ESP_OK) {
        ESP_LOGE(TAG, "Web server start failed!");
    } else {
        ESP_LOGI(TAG, "Web server started on port 80");
    }

    // ==========================================================================
    // Initialize MQTT (only if WiFi connected in STA mode)
    // ==========================================================================
    if (wifi_manager_is_connected()) {
        ESP_LOGI(TAG, "Initializing MQTT...");
        if (mqtt_ha_init() != ESP_OK) {
            ESP_LOGE(TAG, "MQTT initialization failed!");
        } else {
            ESP_LOGI(TAG, "Starting MQTT client...");
            if (mqtt_ha_start() != ESP_OK) {
                ESP_LOGW(TAG, "MQTT start failed - continuing without MQTT");
            } else {
                ESP_LOGI(TAG, "MQTT client started");
            }
        }
    } else {
        ESP_LOGW(TAG, "WiFi not connected - MQTT disabled");
    }

    printf("\n--- Waiting for frames ---\n\n");

    // Main loop - process decoded frames, MQTT, and print statistics
    dlbus_frame_t frame;
    TickType_t last_stats_time = xTaskGetTickCount();

    while (1) {
        // Check for decoded frames
        if (xQueueReceive(frame_queue, &frame, pdMS_TO_TICKS(100)) == pdTRUE) {
            // Print frame to serial
            print_frame(&frame);

            // Process frame for MQTT publishing
            process_frame_for_mqtt(&frame);
        }

        // Run MQTT loop (handles publish intervals)
        mqtt_ha_loop();

        // Print statistics every 10 seconds
        TickType_t now = xTaskGetTickCount();
        if ((now - last_stats_time) >= pdMS_TO_TICKS(10000)) {
            printf("\n--- Pipeline Statistics (GPIO Interrupt) ---\n");
            printf("  Edges captured:  %lu\n", (unsigned long)stat_edges_received);
            printf("  Pulses: short=%lu, long=%lu, midgap=%lu, invalid=%lu\n",
                   (unsigned long)stat_short_pulses, (unsigned long)stat_long_pulses,
                   (unsigned long)stat_midgap_pulses, (unsigned long)stat_invalid_pulses);
            printf("  Gaps detected:   %lu\n", (unsigned long)stat_gaps_detected);
            printf("  Bits extracted:  %lu\n", (unsigned long)stat_bits_extracted);
            printf("  Last frame bits: %lu (need %d)\n", (unsigned long)debug_last_frame_bits, FRAME_BYTES * 10);
            printf("  SYNCs detected:  %lu\n", (unsigned long)stat_syncs_detected);
            printf("  Frames decoded:  %lu\n", (unsigned long)stat_frames_decoded);
            printf("  Frames valid:    %lu\n", (unsigned long)stat_frames_valid);
            printf("  Edge buffer:     %lu/%d\n", (unsigned long)edge_buffer_count(&edge_buffer), EDGE_BUFFER_SIZE);
            printf("  Bit queue:       %lu/%d\n", (unsigned long)uxQueueMessagesWaiting(bit_queue), BIT_QUEUE_SIZE);
            printf("  WiFi mode:       %s\n", wifi_manager_is_ap_mode() ? "AP" : "STA");
            printf("  MQTT connected:  %s\n", mqtt_ha_is_connected() ? "Yes" : "No");
            printf("  Webserver:       %s\n", webserver_is_running() ? "Running" : "Stopped");
            printf("--------------------------------------------\n\n");
            last_stats_time = now;
        }
    }
}

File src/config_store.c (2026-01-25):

/**
 * UVR1611 DL-Bus Reader - Configuration Storage Implementation
 *
 * NVS-backed configuration with secure credential handling.
 *
 * Storage layout:
 * - Namespace "uvr_config": Non-secret settings
 * - Namespace "uvr_secret": WiFi/MQTT credentials (never logged)
 *
 * Security:
 * - Secrets are NEVER logged, printed, or returned as pointers
 * - All secret getters copy to caller-provided buffers
 * - Kconfig has NO defaults for secrets
 */

#include <string.h>
#include <stdlib.h>
#include "freertos/FreeRTOS.h"
#include "freertos/semphr.h"
#include "nvs_flash.h"
#include "nvs.h"
#include "esp_log.h"
#include "sdkconfig.h"

#include "config_store.h"
#include "io_config.h"

static const char *TAG = "CONFIG";

// =============================================================================
// NVS Namespaces and Keys
// =============================================================================

#define NVS_NAMESPACE_CONFIG    "uvr_config"
#define NVS_NAMESPACE_SECRET    "uvr_secret"

// Non-secret keys
#define KEY_VERSION             "version"
#define KEY_HOSTNAME            "hostname"
#define KEY_MQTT_URI            "mqtt_uri"
#define KEY_MQTT_CLIENT_ID      "mqtt_client"
#define KEY_MQTT_BASE_TOPIC     "mqtt_topic"
#define KEY_HA_DISC_PREFIX      "ha_prefix"
#define KEY_INTERVAL_SENSORS    "int_sensors"
#define KEY_INTERVAL_OUTPUTS    "int_outputs"
#define KEY_INTERVAL_SYSTEM     "int_system"
#define KEY_INTERVAL_DISCOVERY  "int_disc"
#define KEY_WIFI_TIMEOUT        "wifi_timeout"
#define KEY_DLBUS_GPIO          "dlbus_gpio"
#define KEY_MQTT_KEEPALIVE      "mqtt_keep"
#define KEY_MQTT_QOS            "mqtt_qos"
#define KEY_MQTT_RETAIN_SENS    "mqtt_ret_s"
#define KEY_MQTT_RETAIN_STAT    "mqtt_ret_st"

// Secret keys (stored in separate namespace)
#define KEY_WIFI_SSID           "wifi_ssid"
#define KEY_WIFI_PASSWORD       "wifi_pass"
#define KEY_MQTT_USERNAME       "mqtt_user"
#define KEY_MQTT_PASSWORD       "mqtt_pass"

// I/O name key prefixes (sensor_0 through sensor_15, output_0 through output_12)
#define KEY_SENSOR_PREFIX       "sensor_"
#define KEY_OUTPUT_PREFIX       "output_"
#define KEY_SPEED_PREFIX        "speed_"
#define KEY_HM_POWER_PREFIX     "hm_pwr_"
#define KEY_HM_ENERGY_PREFIX    "hm_nrg_"

// =============================================================================
// Runtime Configuration Storage
// =============================================================================

// Non-secret configuration (loaded at init, cached in RAM)
typedef struct {
    char hostname[CONFIG_HOSTNAME_MAX_LEN];
    char mqtt_broker_uri[CONFIG_MQTT_URI_MAX_LEN];
    char mqtt_client_id[CONFIG_MQTT_CLIENT_ID_MAX_LEN];
    char mqtt_base_topic[CONFIG_MQTT_TOPIC_MAX_LEN];
    char ha_discovery_prefix[CONFIG_MQTT_TOPIC_MAX_LEN];
    char sensor_names[CONFIG_NUM_SENSORS][CONFIG_IO_NAME_MAX_LEN];
    char output_names[CONFIG_NUM_OUTPUTS][CONFIG_IO_NAME_MAX_LEN];
    char speed_names[CONFIG_NUM_SPEED_LEVELS][CONFIG_IO_NAME_MAX_LEN];
    char heat_meter_power_names[CONFIG_NUM_HEAT_METERS][CONFIG_IO_NAME_MAX_LEN];
    char heat_meter_energy_names[CONFIG_NUM_HEAT_METERS][CONFIG_IO_NAME_MAX_LEN];
    uint16_t interval_sensors;
    uint16_t interval_outputs;
    uint16_t interval_system;
    uint16_t interval_discovery;
    uint16_t wifi_timeout;
    uint16_t mqtt_keepalive;
    uint8_t dlbus_gpio;
    uint8_t mqtt_qos;
    bool mqtt_retain_sensors;
    bool mqtt_retain_status;
    uint8_t version;
} config_data_t;

static config_data_t s_config;
static bool s_initialized = false;
static SemaphoreHandle_t s_mutex = NULL;

// =============================================================================
// Internal Helpers
// =============================================================================

static void lock(void)
{
    if (s_mutex) {
        xSemaphoreTake(s_mutex, portMAX_DELAY);
    }
}

static void unlock(void)
{
    if (s_mutex) {
        xSemaphoreGive(s_mutex);
    }
}

/**
 * Load string from NVS, or use default if not found
 */
static void load_string(nvs_handle_t handle, const char *key,
                        char *dest, size_t dest_len, const char *default_val)
{
    size_t len = dest_len;
    esp_err_t err = nvs_get_str(handle, key, dest, &len);
    if (err != ESP_OK) {
        strncpy(dest, default_val, dest_len - 1);
        dest[dest_len - 1] = '\0';
    }
}

/**
 * Load uint16 from NVS, or use default if not found
 */
static uint16_t load_u16(nvs_handle_t handle, const char *key, uint16_t default_val)
{
    uint16_t value;
    if (nvs_get_u16(handle, key, &value) != ESP_OK) {
        return default_val;
    }
    return value;
}

/**
 * Load uint8 from NVS, or use default if not found
 */
static uint8_t load_u8(nvs_handle_t handle, const char *key, uint8_t default_val)
{
    uint8_t value;
    if (nvs_get_u8(handle, key, &value) != ESP_OK) {
        return default_val;
    }
    return value;
}
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

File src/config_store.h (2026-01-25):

/**
 * UVR1611 DL-Bus Reader - Configuration Storage Abstraction
 *
 * Provides secure, NVS-backed configuration storage with:
 * - Non-secret config: Kconfig defaults with NVS override
 * - Secret config: NVS only (WiFi/MQTT credentials)
 *
 * Security guarantees:
 * - Secrets NEVER appear in source code, headers, or logs
 * - Secrets exist only in NVS at runtime
 * - All secret getters copy to caller-provided buffers
 */

#ifndef CONFIG_STORE_H
#define CONFIG_STORE_H

#include <stdbool.h>
#include <stdint.h>
#include "esp_err.h"

#ifdef __cplusplus
extern "C" {
#endif

// =============================================================================
// Constants
// =============================================================================

// Maximum lengths for configuration values (including null terminator)
#define CONFIG_HOSTNAME_MAX_LEN         32
#define CONFIG_WIFI_SSID_MAX_LEN        33   // 802.11 max SSID = 32 bytes
#define CONFIG_WIFI_PASSWORD_MAX_LEN    64
#define CONFIG_MQTT_URI_MAX_LEN         128
#define CONFIG_MQTT_USERNAME_MAX_LEN    64
#define CONFIG_MQTT_PASSWORD_MAX_LEN    64
#define CONFIG_MQTT_CLIENT_ID_MAX_LEN   32
#define CONFIG_MQTT_TOPIC_MAX_LEN       64
#define CONFIG_IO_NAME_MAX_LEN          24   // Max length for sensor/output names

// Number of I/O channels
#define CONFIG_NUM_SENSORS              16
#define CONFIG_NUM_OUTPUTS              13
#define CONFIG_NUM_SPEED_LEVELS         4
#define CONFIG_NUM_HEAT_METERS          2

// Current configuration version (increment on schema changes)
#define CONFIG_VERSION                  1

// =============================================================================
// Initialization
// =============================================================================

/**
 * Initialize the configuration store
 *
 * Must be called once at startup before any other config functions.
 * Initializes NVS, loads defaults from Kconfig, applies NVS overrides.
 *
 * @return ESP_OK on success, error code on failure
 */
esp_err_t config_store_init(void);

/**
 * Check if configuration store is initialized
 *
 * @return true if initialized, false otherwise
 */
bool config_store_is_initialized(void);

// =============================================================================
// Non-Secret Configuration (Kconfig defaults with NVS override)
// =============================================================================

// --- Device Settings ---

/**
 * Get device hostname
 * @return Hostname string (valid until next set or reboot)
 */
const char *config_get_hostname(void);

/**
 * Set device hostname
 * @param hostname New hostname (max CONFIG_HOSTNAME_MAX_LEN-1 chars)
 * @return ESP_OK on success
 */
esp_err_t config_set_hostname(const char *hostname);

// --- MQTT Settings (non-secret) ---

/**
 * Get MQTT broker URI
 * @return URI string (e.g., "mqtt://192.168.1.100:1883")
 */
const char *config_get_mqtt_broker_uri(void);

/**
 * Set MQTT broker URI
 * @param uri New broker URI
 * @return ESP_OK on success
 */
esp_err_t config_set_mqtt_broker_uri(const char *uri);

/**
 * Get MQTT client ID
 * @return Client ID string
 */
const char *config_get_mqtt_client_id(void);

/**
 * Set MQTT client ID
 * @param client_id New client ID
 * @return ESP_OK on success
 */
esp_err_t config_set_mqtt_client_id(const char *client_id);

/**
 * Get MQTT base topic
 * @return Base topic string (e.g., "uvr1611")
 */
const char *config_get_mqtt_base_topic(void);

/**
 * Set MQTT base topic
 * @param topic New base topic
 * @return ESP_OK on success
 */
esp_err_t config_set_mqtt_base_topic(const char *topic);

/**
 * Get Home Assistant discovery prefix
 * @return Discovery prefix string (e.g., "homeassistant")
 */
const char *config_get_ha_discovery_prefix(void);

/**
 * Set Home Assistant discovery prefix
 * @param prefix New discovery prefix
 * @return ESP_OK on success
 */
esp_err_t config_set_ha_discovery_prefix(const char *prefix);

// --- Timing Settings ---

/**
 * Get sensor publish interval in seconds
 * @return Interval in seconds
 */
uint16_t config_get_publish_interval_sensors(void);

/**
 * Set sensor publish interval
 * @param seconds Interval in seconds (1-3600)
 * @return ESP_OK on success
 */
esp_err_t config_set_publish_interval_sensors(uint16_t seconds);

/**
 * Get output publish interval in seconds
 * @return Interval in seconds
 */
uint16_t config_get_publish_interval_outputs(void);

/**
 * Set output publish interval
 * @param seconds Interval in seconds (1-3600)
 * @return ESP_OK on success
 */
esp_err_t config_set_publish_interval_outputs(uint16_t seconds);

/**
 * Get system info publish interval in seconds
 * @return Interval in seconds
 */
uint16_t config_get_publish_interval_system(void);

/**
 * Set system info publish interval
 * @param seconds Interval in seconds (1-3600)
 * @return ESP_OK on success
 */
esp_err_t config_set_publish_interval_system(uint16_t seconds);
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

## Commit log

2026-01-21 Initial commit: UVR1611 DL-Bus reader with GPIO interrupt capture
    Phase 1 complete:
    - GPIO interrupt-based edge capture (replaced RMT due to buffer limits)
    - Pipeline architecture: GPIO ISR -> Edge Buffer -> Bit Extractor -> Manchester Decoder
    - Full 64-byte frame capture with valid checksums
    - SYNC detection, device ID verification, timestamp parsing
    - Statistics and debug output
    Hardware: D1 Mini ESP32 on GPIO26
    Protocol: 488 Hz Manchester-like encoding, 2.048ms bit duration
    [main.c]
2026-01-22 Optimize GPIO ISR for better capture rate
    - Remove semaphore signaling from ISR (task polls instead)
    - Inline buffer write for minimal latency
    - Use higher ISR priority (LEVEL3)
    - Widen pulse filter range (500-10000us) for tolerance
    - Reduce branching in hot path
    [main.c]
2026-01-22 Add I/O configuration and sensor/output parsing
    - Add Kconfig.projbuild for menuconfig integration (sensor names, output
    names, speed levels, units)
    - Add io_config.h header with array macros from Kconfig values
    - Add frame parsing functions for sensors, outputs, speed levels, heat meters
    - Update print_frame() to show all values with configured names
    - Fix room sensor decoding (type 0x70 uses only low byte for temperature)
    - Update platformio.ini with menuconfig comment
    [io_config.h, main.c]
2026-01-22 Add MQTT and Home Assistant integration
    Features:
    - WiFi connection with auto-reconnect
    - MQTT client with LWT for online/offline status
    - Home Assistant auto-discovery for all entities
    - Sensor values published as median (every 30s configurable)
    - Output states published immediately on change
    - Speed levels published immediately on change
    - Heat meter data publishing
    - System info (MAC, IP, uptime) via MQTT
    Configuration:
    - wifi_config.h.example template (wifi_config.h excluded from git)
    - Configurable publish intervals
    - Configurable MQTT broker, topics, QoS
    New files:
    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
    [main.c]
2026-01-22 Fix DL-Bus timing interference from WiFi
    - Pin bit_extractor and manchester_decoder tasks to Core 1
    - WiFi/MQTT runs on Core 0 (default)
    - Initialize DL-Bus pipeline BEFORE WiFi starts
    - Add 2s stabilization delay before WiFi init
    - Increase task priorities for timing-critical tasks
    This prevents WiFi interrupts from corrupting DL-Bus timing.
    [main.c]
2026-01-24 Fix Kconfig bool handling for MQTT retain options
    ESP-IDF Kconfig bool options with default=n don't define the CONFIG_*
    macro at all. Changed to use #ifdef checks instead of direct assignment.
    [config_store.c]
2026-01-24 Add web UI screenshots to README
    - Add pictures/ folder with screenshots of the configuration interface
    - Update README.md with Screenshots section showing:
    - Status overview page
    - Live sensor data display
    - Output states
    - WiFi configuration form
    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
2026-01-24 Fix heat meter publishing to use interval instead of every frame
    Heat meters were being published on every DL-Bus frame instead of
    respecting the configured sensor publish interval.
    Changes:
    - Add heat_meter_buffer_t for buffering power/energy samples
    - Replace mqtt_ha_publish_heat_meter() with mqtt_ha_add_heat_meter_sample()
    - Add mqtt_ha_publish_heat_meters() that calculates median and publishes
    - Call mqtt_ha_publish_heat_meters() in mqtt_ha_loop() on sensor interval
    - Update main.c to use the new sampling function
    Now heat meter values are buffered and published as median values on
    the same interval as temperature sensors.
    [main.c]
2026-01-24 Add web UI for editing sensor and output names
    Configuration changes:
    - Add sensor_names and output_names arrays to config_store
    - Add config_get_sensor_name() and config_get_output_name() getters
    - Add config_set_sensor_name() and config_set_output_name() setters
    - Add config_reset_io_names() to restore Kconfig defaults
    - Names stored in NVS with Kconfig fallback
    Code updates:
    - Remove static sensor_names/output_names arrays from mqtt_ha.c, main.c, webserver.c
    - Replace all usages with config_get_sensor_name(i) and config_get_output_name(i)
    Web interface:
    - Add I/O Names section to /config page with forms for S1-S16 and A1-A13
    - Add POST /config/io endpoint to save names
    - Increase config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
    [config_store.c, config_store.h, main.c]
2026-01-24 Add OTA firmware update via web interface
    Partition table:
    - Create partitions.csv with two OTA partitions (1.75MB each)
    - Update platformio.ini to use custom partition table
    - Add firmware update section to /config page
    - Show current version, build date/time
    - File picker for .bin firmware files
    - JavaScript-based upload with progress indicator
    - POST /ota endpoint handles binary firmware upload
    OTA implementation:
    - Validate firmware header magic number
    - Write to next OTA partition in 4KB chunks
    - Set new partition as boot partition on success
    - Auto-reboot after successful update
    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
    [partitions.csv]
2026-01-24 Fix system info interval and use hostname in HA discovery
    1. System info (MAC, IP, uptime) now publishes on the sensor interval
    instead of a separate system interval - all data publishes together
    2. Home Assistant discovery now uses hostname from config as device name
    instead of hardcoded "UVR1611 Gateway"
    - Sensor discovery uses config_get_hostname()
    - Binary sensor discovery uses config_get_hostname()
    - Uptime sensor renamed from "UVR1611 Uptime" to just "Uptime"
    Changing the hostname will update the device name in Home Assistant
    after a reboot (when discovery is re-published).
2026-01-24 Update documentation for recent features
    CLAUDE.md:
    - Add OTA firmware update section
    - Add I/O name APIs to key APIs section
    - Add partitions.csv to key files
    - Update web endpoints list
    - Note system info publishes with sensors
    README.md:
    - Add OTA update to web configuration features
    - Add sensor/output name editing instructions
    - Add OTA firmware update section
    - Update Home Assistant section (hostname-based device name)
    - Update status to "All Phases Complete"
    prompt_history.txt:
    - Add Iteration 9 documenting:
    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
2026-01-24 PCB files added
    [UVR2MQTT-B_Cu.gbr, UVR2MQTT-B_Mask.gbr, UVR2MQTT-B_Paste.gbr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]
2026-01-24 Add Home Assistant autodiscovery for diagnostic entities
    - Add autodiscovery for IP address, MAC address, and connectivity status
    - Fix IP address not being published (was never fetched from wifi_manager)
    - All three entities appear in HA diagnostic section
    - Update documentation with PCB folder reference and new entities
2026-01-25 Add configurable speed level and heat meter names with name filtering
    - Speed level names (Drehzahlstufen A1, A2, A6, A7) now editable via web UI
    - Heat meter power/energy names (WMZ1/WMZ2) now editable via web UI
    - Only entities with configured names (containing alphanumeric chars) are:
    - Published to MQTT
    - Registered in Home Assistant autodiscovery
    - Names with only "-" chars (like "---") or empty names disable the entity
    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
2026-01-25 Split configuration page into Device Settings and I/O Names sub-pages
    - /config: WiFi, Hostname, MQTT settings, Firmware Update
    - /config/io-names: Sensors, Outputs, Speed Levels, Heat Meters
    - Each page has its own save button and reboot button
    - Updated navigation to show both configuration pages
    - Improved user experience with smaller, focused configuration pages
2026-01-25 Fix Save & Reboot button to save I/O names before rebooting
    The button was in a separate form that only posted to /reboot without
    saving the form data first. Now uses JavaScript to submit the I/O form
    via AJAX, then triggers reboot only after successful save.
2026-01-25 Update prompt_history.txt with Save & Reboot bug fix (Iteration 12)
    Documented the fix for the Save & Reboot button on the I/O Names page
    that was rebooting without saving settings first.
2026-01-25 Fix compiler warnings in main.c
    - Remove unused edge_buffer_put() function
    - Simplify gpio_dedicated_isr() by removing GPIO >= 32 branch
    (DL_BUS_GPIO is always 26, which is < 32)
    [main.c]
2026-01-25 Restore GPIO >= 32 support in gpio_dedicated_isr
    Use preprocessor #if instead of runtime if to avoid compiler warning
    while maintaining support for any GPIO pin number.
    [main.c]
